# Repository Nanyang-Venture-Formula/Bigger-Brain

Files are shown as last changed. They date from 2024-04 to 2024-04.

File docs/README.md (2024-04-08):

# Bigger Brain (Rev 2.1)

This repository contains all documents regarding the Bigger Brain board.

### Shortcuts
- [Schematics](#Schematics)
- [Assembly](#Assembly)
- [Renders](#Renders)
- [Bom](#Bom)

---

## Schematics



## Assembly




## Renders

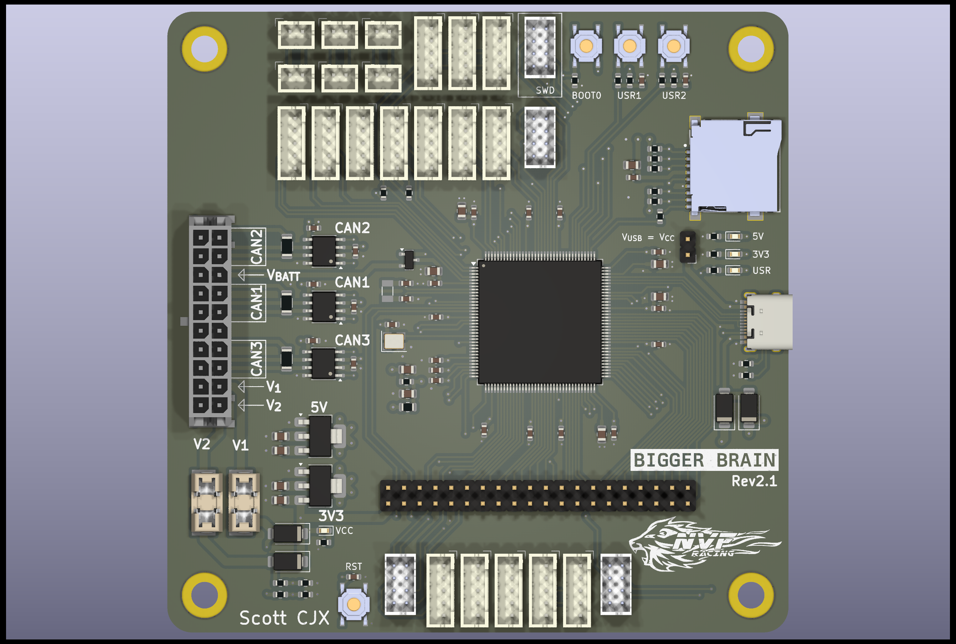
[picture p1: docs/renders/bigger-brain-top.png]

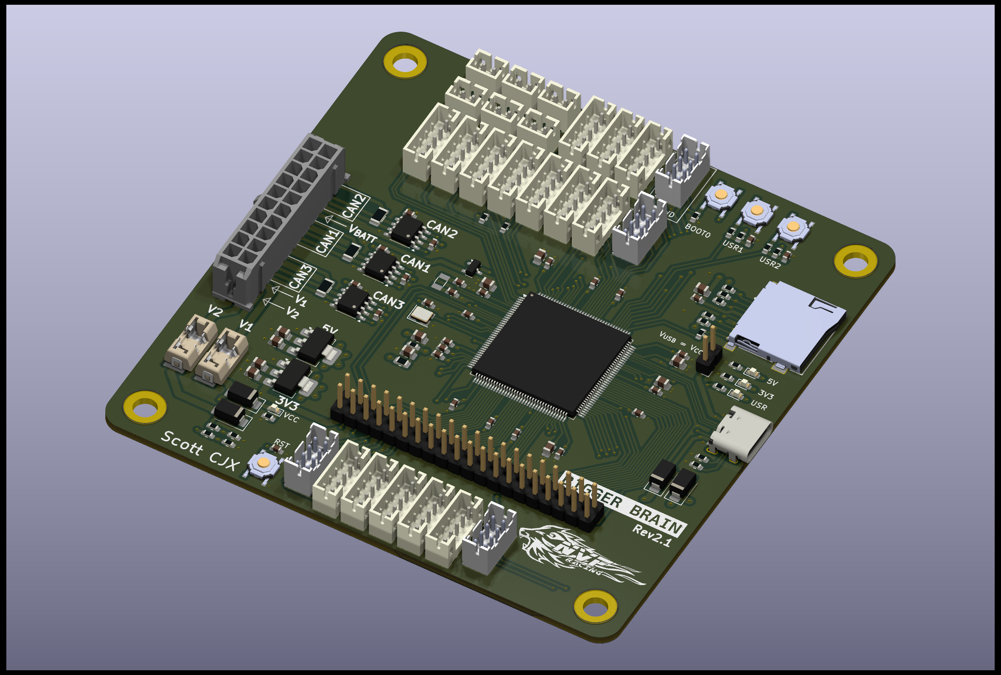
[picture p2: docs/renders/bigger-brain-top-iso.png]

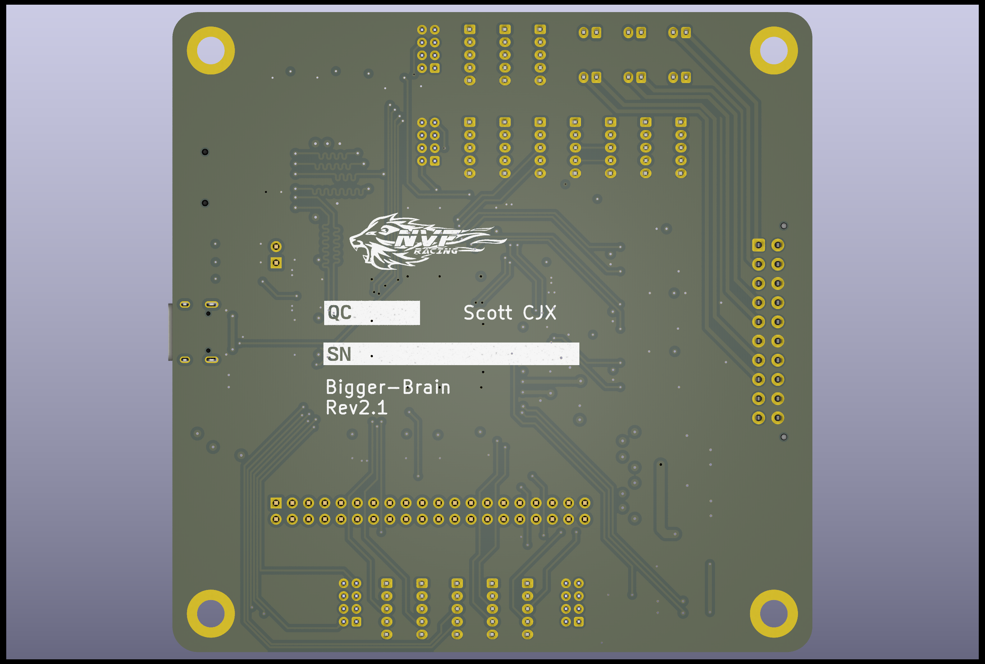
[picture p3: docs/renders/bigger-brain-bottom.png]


## Bom

[Interactive BOM](./ibom/ibom.html)

[BOM](./bom/bigger-brain.csv)

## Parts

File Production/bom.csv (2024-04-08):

Designator | Footprint | Quantity | Value | LCSC Part #
C101, C201, C202, C203, C204, C205, C206, C207, C208, C209, C210, C211, C213, C215, C217, C221, C301, C401, C402, C403, C501, C502, C601, C602, C701, C702 | 0603 | 26 | 100n | C14663
C103, C104 | 0603 | 2 | 15p | C1644
C212 | 0805 | 1 | 4u7 | C1779
C214, C216, C218, C222, C302 | 0805 | 5 | 1u | C28323
C219, C220, C223, C224, C227, C228 | 0805 | 6 | 2u2 | C377773
D201 | SOT-23 | 1 | BAV70 | C68978
D202, D203, D401, D402 | D_SMA | 4 | SS14 | C2480
D403 | 0603 | 1 | GREEN | C434423
D404 | 0603 | 1 | RED | C2286
D405, D406 | 0603 | 2 | BLUE | C965807
F201, F202 | FUSE-Littelfuse_Nano2_154x | 2 | 1A | C206910
H401, H402, H403, H404 | MountingHole_4.3mm_M4_DIN965_Pad_TopBottom | 4 | M4 Pad | -
J301 | TFCard_TF-01A | 1 | TF-01A | C91145
J401 | USBC_HRO_TYPE-C-31-M-12 | 1 | USB_C | C165948
J402 | MicroFit_02x10V-H | 1 | Molex_Micro-Fit_3.0_43045-2012_2x10_P3.00mm_Vertical | C485575
J403 | 2.54mm2x20V-H | 1 | 2x20V-H | C2894981
J404, J405, J406, J410, J411, J412 | PH_01x02V-H | 6 | Conn_01x02 | C2683610
J407, J408, J409 | PH_01x05V-H | 3 | I2C Breakout | C157993
J413, J415, J416, J417, J418, J419, J422, J425, J426 | PH_01x05V-H | 9 | Generic Breakout | C157993
J414, J423, J424 | PH_01x05V-H | 3 | UART Breakout | C157993
J420, J421, J427 | PHD_02x04V-H | 3 | SPI Breakout | C157975
JP401 | PinHeader_1x02_P2.54mm_Vertical | 1 | Jumper_2_Open | -
L201 | 0805 | 1 | 100MHz | C1015
R101, R102, R202, R204, R401, R402 | 0603 | 6 | 5k1 | C23186
R201 | 0603 | 1 | 47 | C23182
R203, R205, R410, R411, R414 | 0603 | 5 | 1k | C21190
R301, R302, R303, R304, R305 | 0603 | 5 | 47k | C25819
R306, R406, R407, R408 | 0603 | 4 | 10k | C25804
R403, R404, R405 | 1206 | 3 | 120 | C17909
R409, R412, R413 | 0603 | 3 | 300 | C23025
SW401, SW402, SW403, SW404 | PushBtn_TS-1187A-B-A-B | 4 | SW_Push | C318884
SWD401 | PHD_02x04V-H | 1 | ~ | C157975
U101 | LQFP-144_20x20mm_P0.5mm | 1 | STM32H723ZGTx | C730146
U201 | SOT-223-3_TabPin2 | 1 | AMS1117-3.3 | C6186
U203 | SOT-223-3_TabPin2 | 1 | AMS1117-5.0 | C6187
U501, U601, U701 | SOIC-8_3.9x4.9mm_P1.27mm | 3 | TJA1042T-3 | C132227
X101 | Crystal_SMD_3225-4Pin_3.2x2.5mm | 1 | 25MHz ±10ppm | C669088
Y101 | Crystal_SMD_3215-2Pin_3.2x1.5mm | 1 | 32.768kHz 12.5pF ±20ppm | C32346

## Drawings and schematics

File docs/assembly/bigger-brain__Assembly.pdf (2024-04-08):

1 | 2 | 3 | 4 | 5 | 6

A

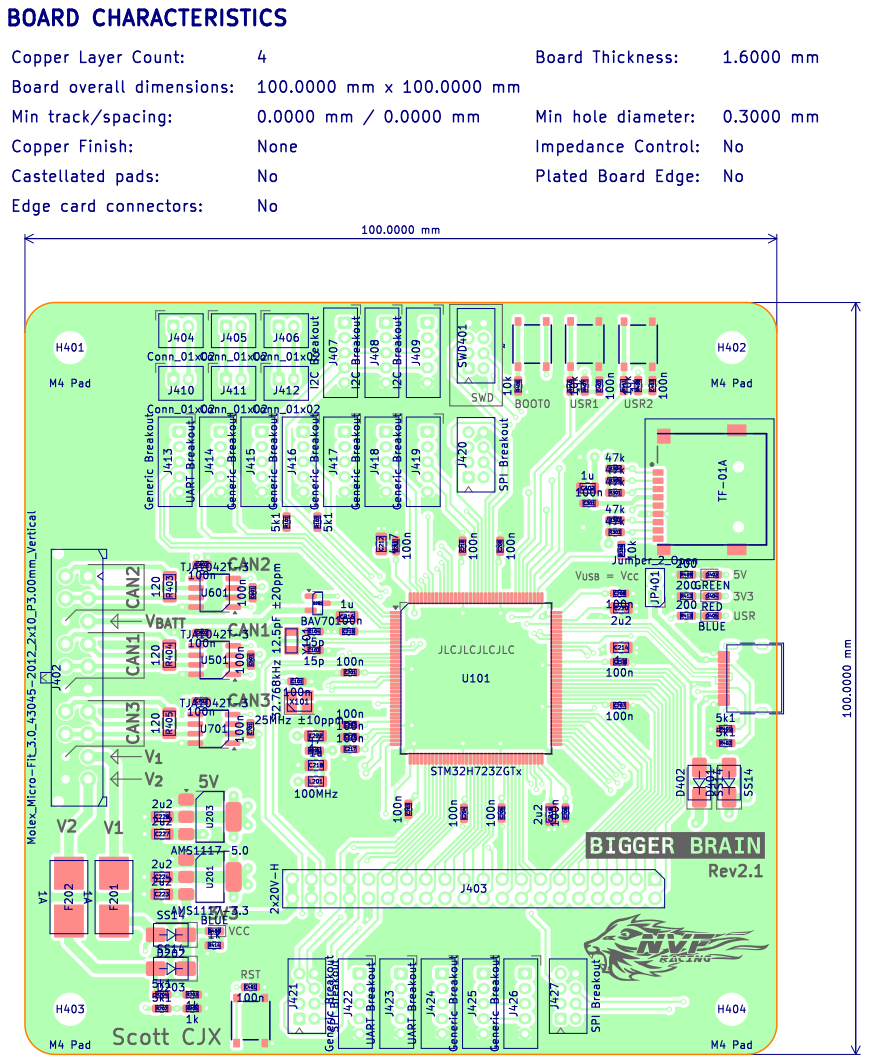
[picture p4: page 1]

File: bigger-brain.kicad_pcb Sheet: Scott CJX

Id: 1/1 Title: Bigger Brain

1 | 2 | 3 | 4 | 5 | 6

A

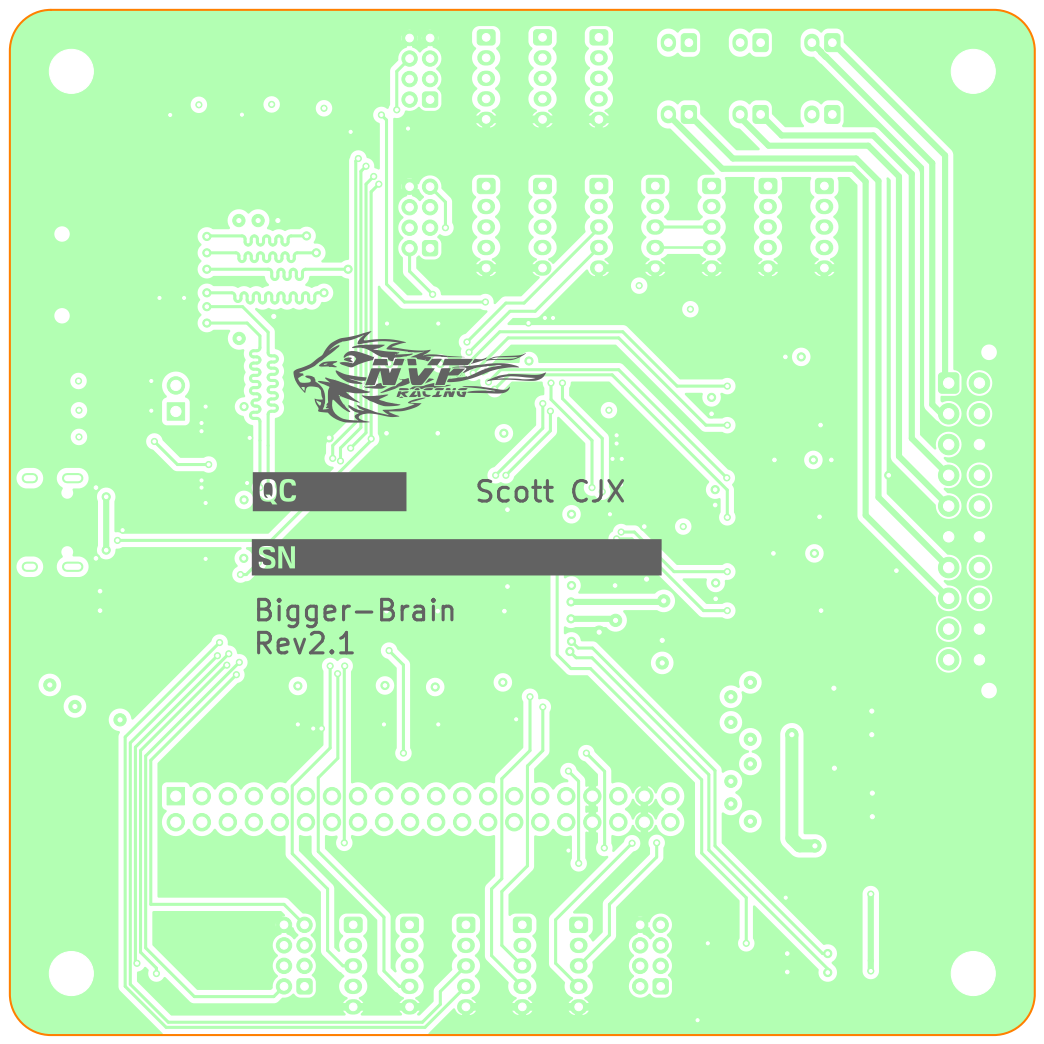
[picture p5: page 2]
Bigger-Brain Rev2.1; Scott; CJX; D Date: 2024-04-08 KiCad; E.D.A. 8.0.1 Size: A4; Rev: 2.1

File: bigger-brain.kicad_pcb Sheet: Scott CJX

Id: 1/1 Title: Bigger Brain

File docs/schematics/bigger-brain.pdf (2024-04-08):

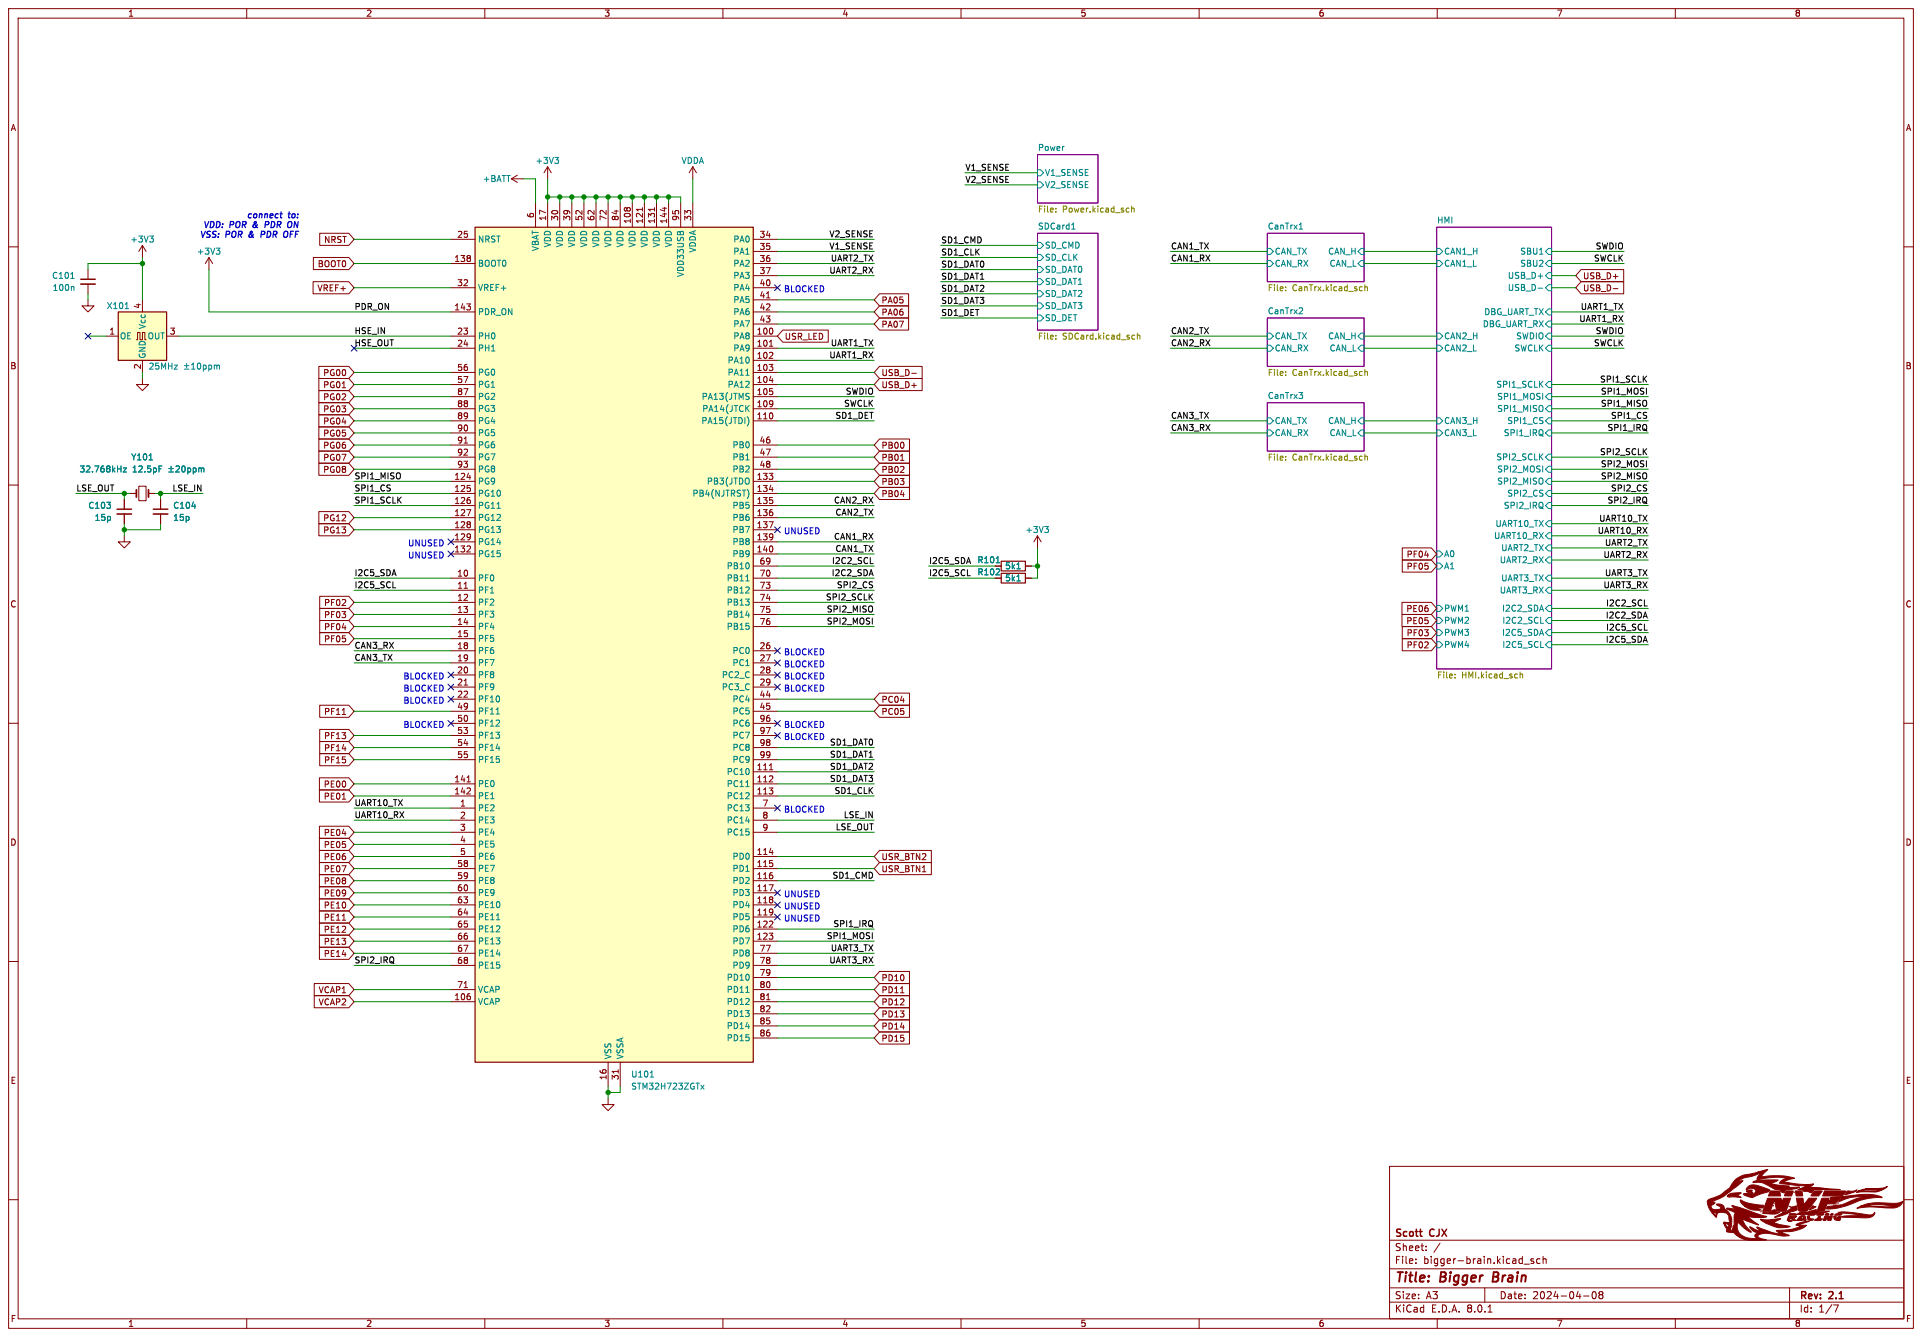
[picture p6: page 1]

Power File: Power.kicad_sch VDDA

connect to: VDD: POR & PDR ON

Id: 1/7 Title: Bigger Brain

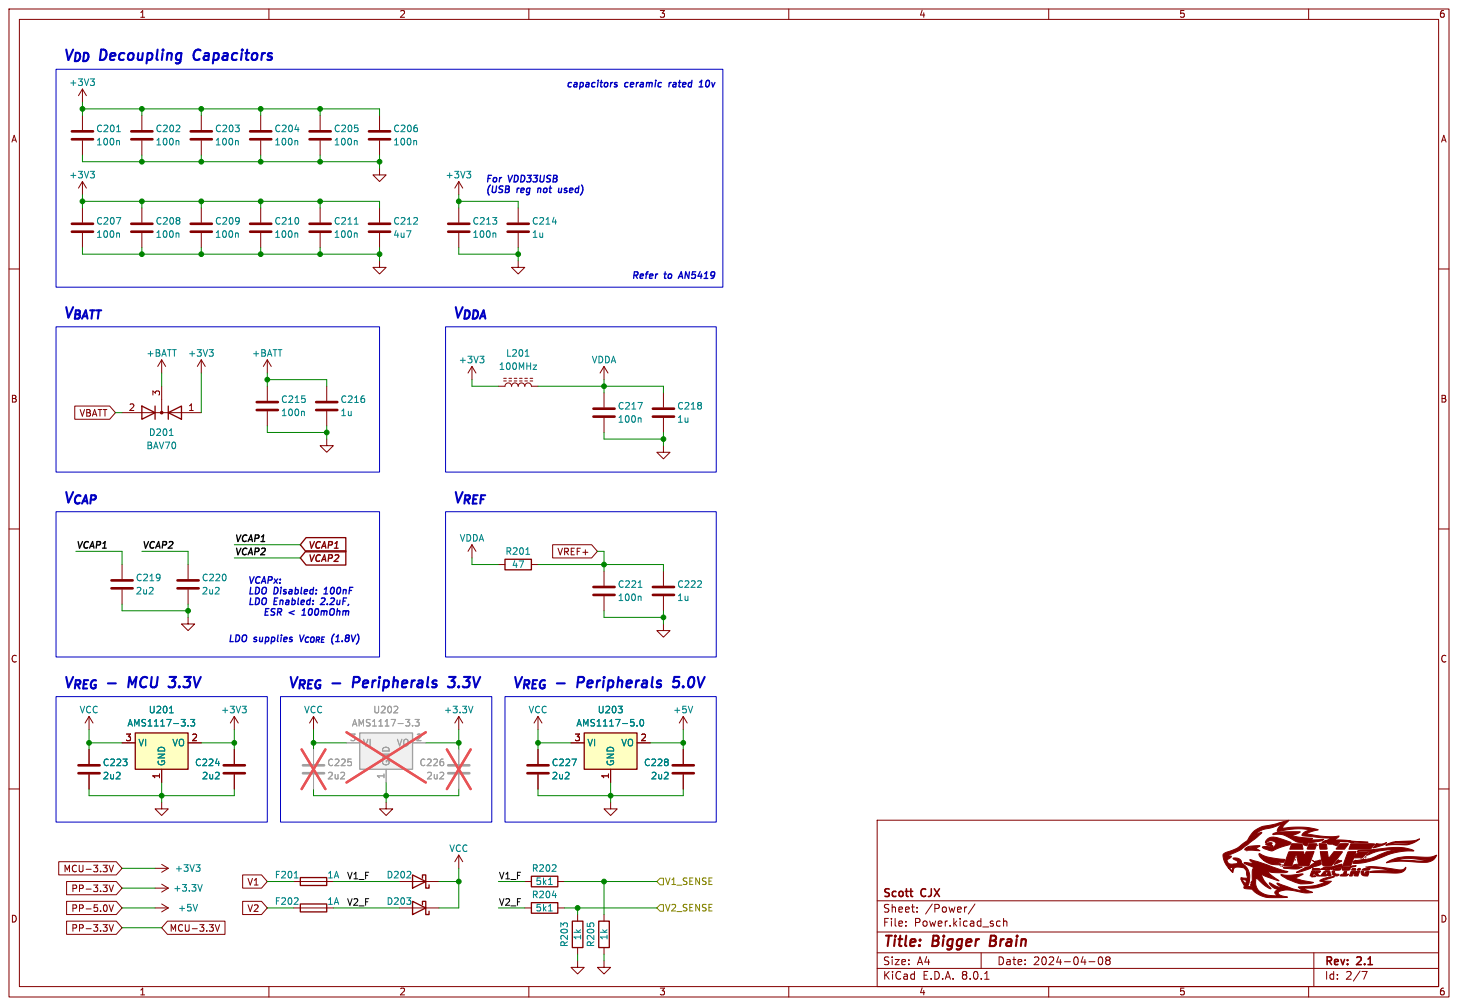
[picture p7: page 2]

capacitors ceramic rated 10v U202 AMS1117-3.3 GND

(USB reg not used)

File: Power.kicad_sch Sheet: /Power/ Scott CJX

Id: 2/7 Title: Bigger Brain

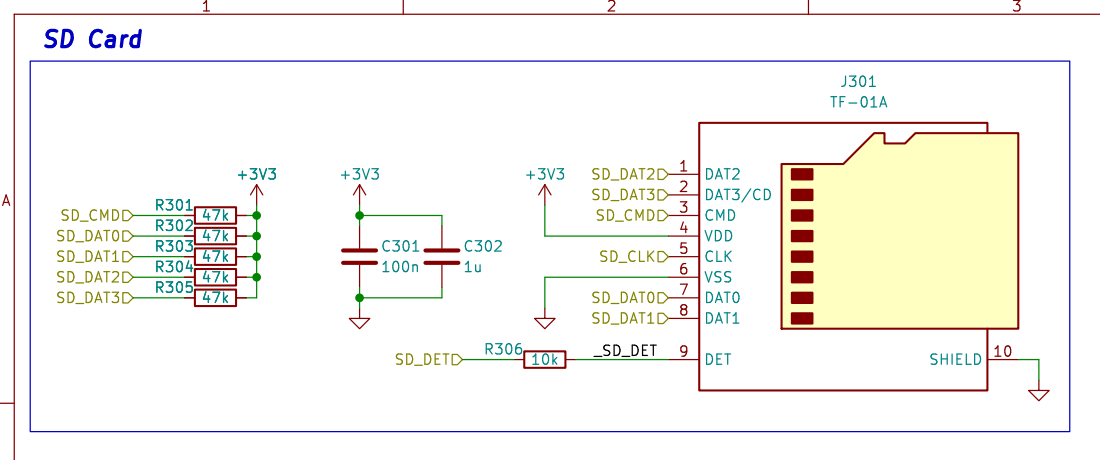
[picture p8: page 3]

File: SDCard.kicad_sch Sheet: /SDCard1/ Scott CJX

Id: 3/7 Title: Bigger Brain

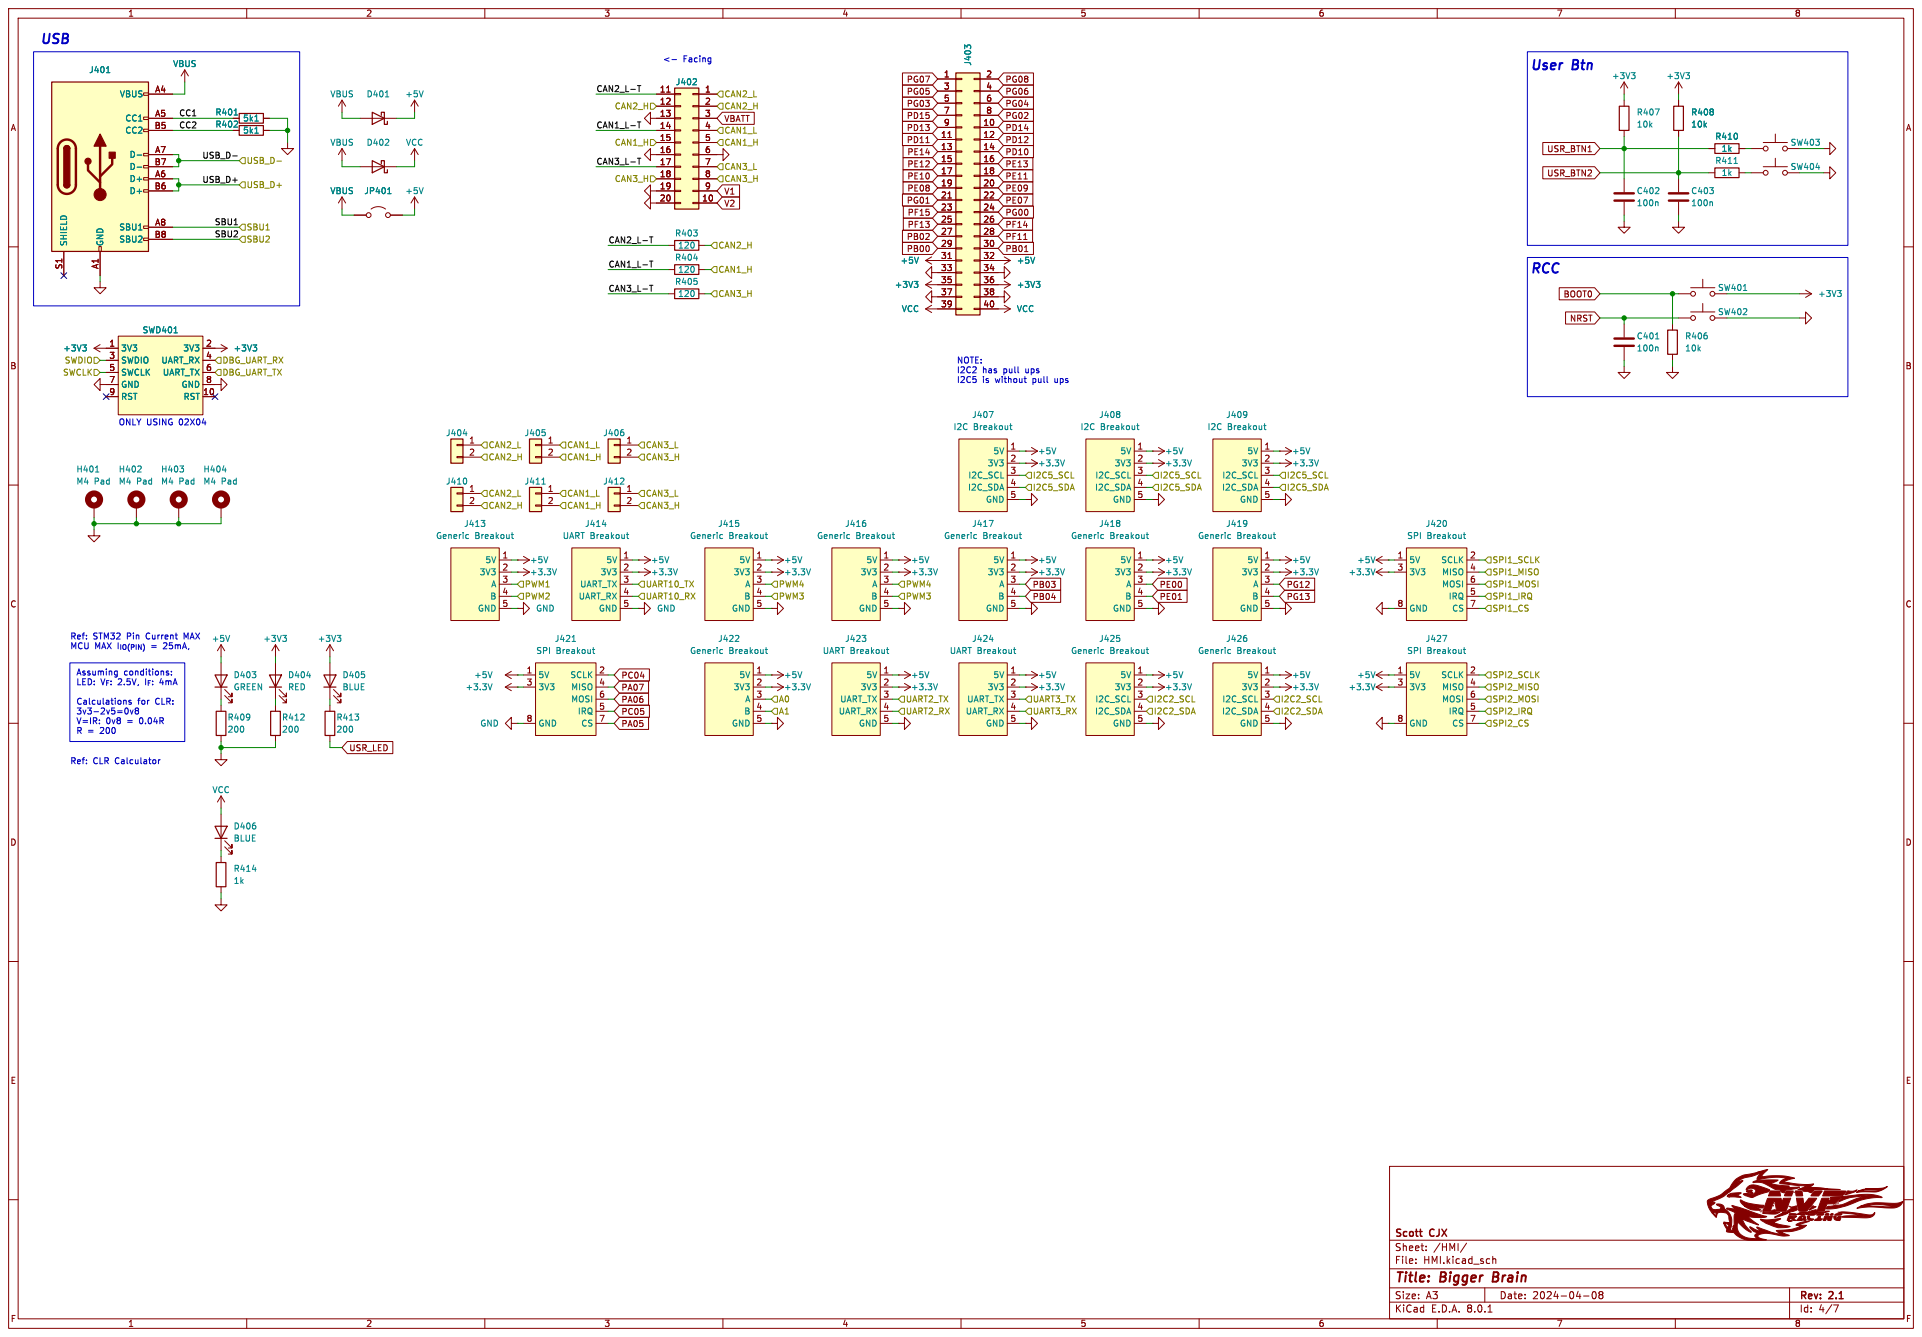
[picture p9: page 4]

I2C5 is without pull ups J403

R = 200 Ref: CLR Calculator Ref: STM32 Pin Current MAX MCU MAX I_{IO(PIN)}= 25mA,

IRQ 5 MOSI 6 CS 7 GND 8

Id: 4/7 Title: Bigger Brain

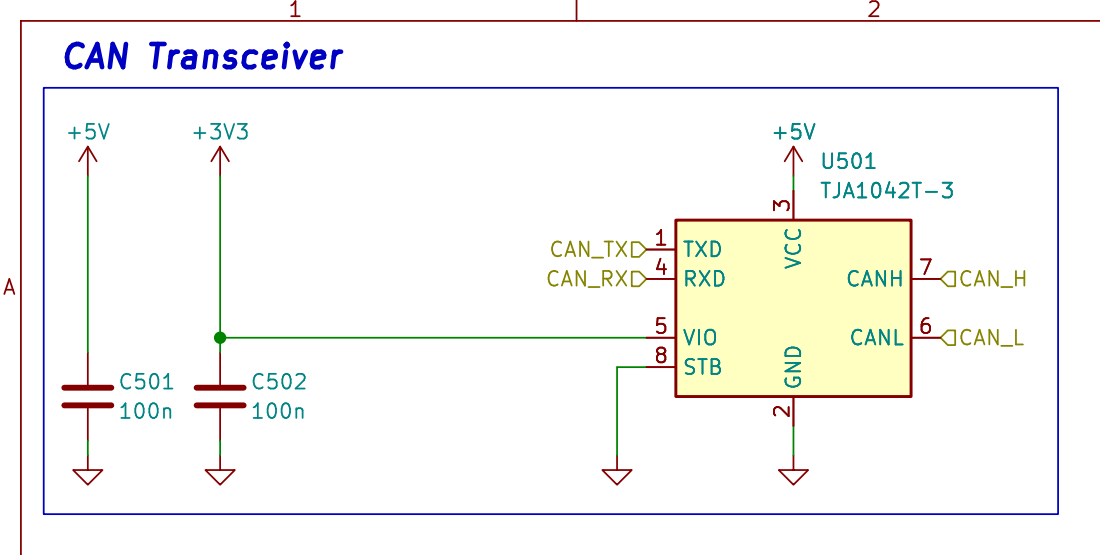
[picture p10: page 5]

3 RXD 4 VIO 5 CANL 6 CANH 7 STB 8 U501 TJA1042T-3 +5V C501

3 RXD 4 VIO 5 CANL 6 CANH 7 STB 8 +5V

File: CanTrx.kicad_sch Sheet: /CanTrx1/ Scott CJX

Id: 5/7 Title: Bigger Brain

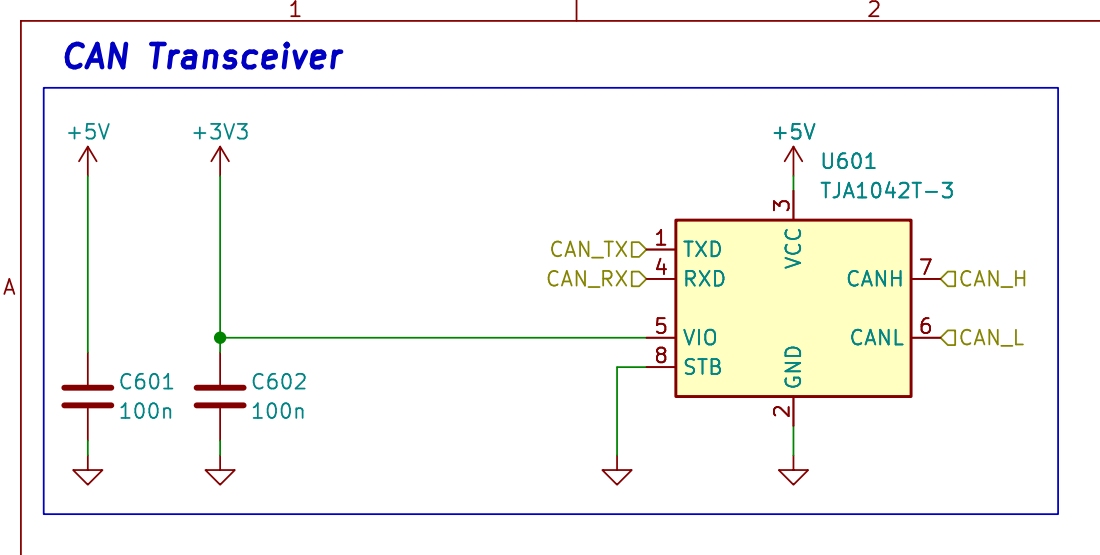
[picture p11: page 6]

3 RXD 4 VIO 5 CANL 6 CANH 7 STB 8 U601 TJA1042T-3 +5V C601

3 RXD 4 VIO 5 CANL 6 CANH 7 STB 8 +5V

File: CanTrx.kicad_sch Sheet: /CanTrx2/ Scott CJX

Id: 6/7 Title: Bigger Brain

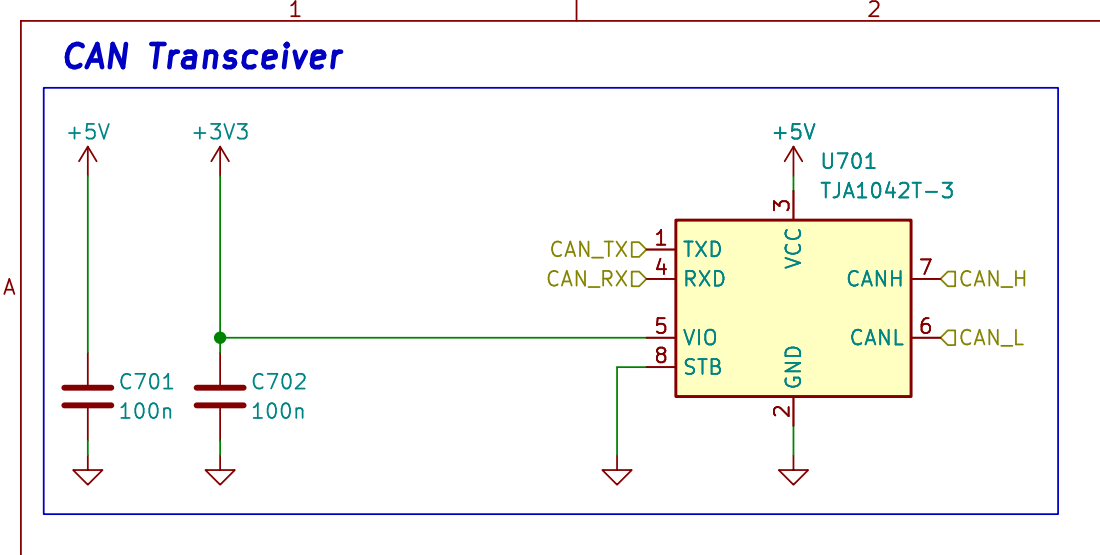
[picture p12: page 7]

3 RXD 4 VIO 5 CANL 6 CANH 7 STB 8 U701 TJA1042T-3 +5V +3V3 +5V C701

3 RXD 4 VIO 5 CANL 6 CANH 7 STB 8 +5V

File: CanTrx.kicad_sch Sheet: /CanTrx3/ Scott CJX

Id: 7/7 Title: Bigger Brain

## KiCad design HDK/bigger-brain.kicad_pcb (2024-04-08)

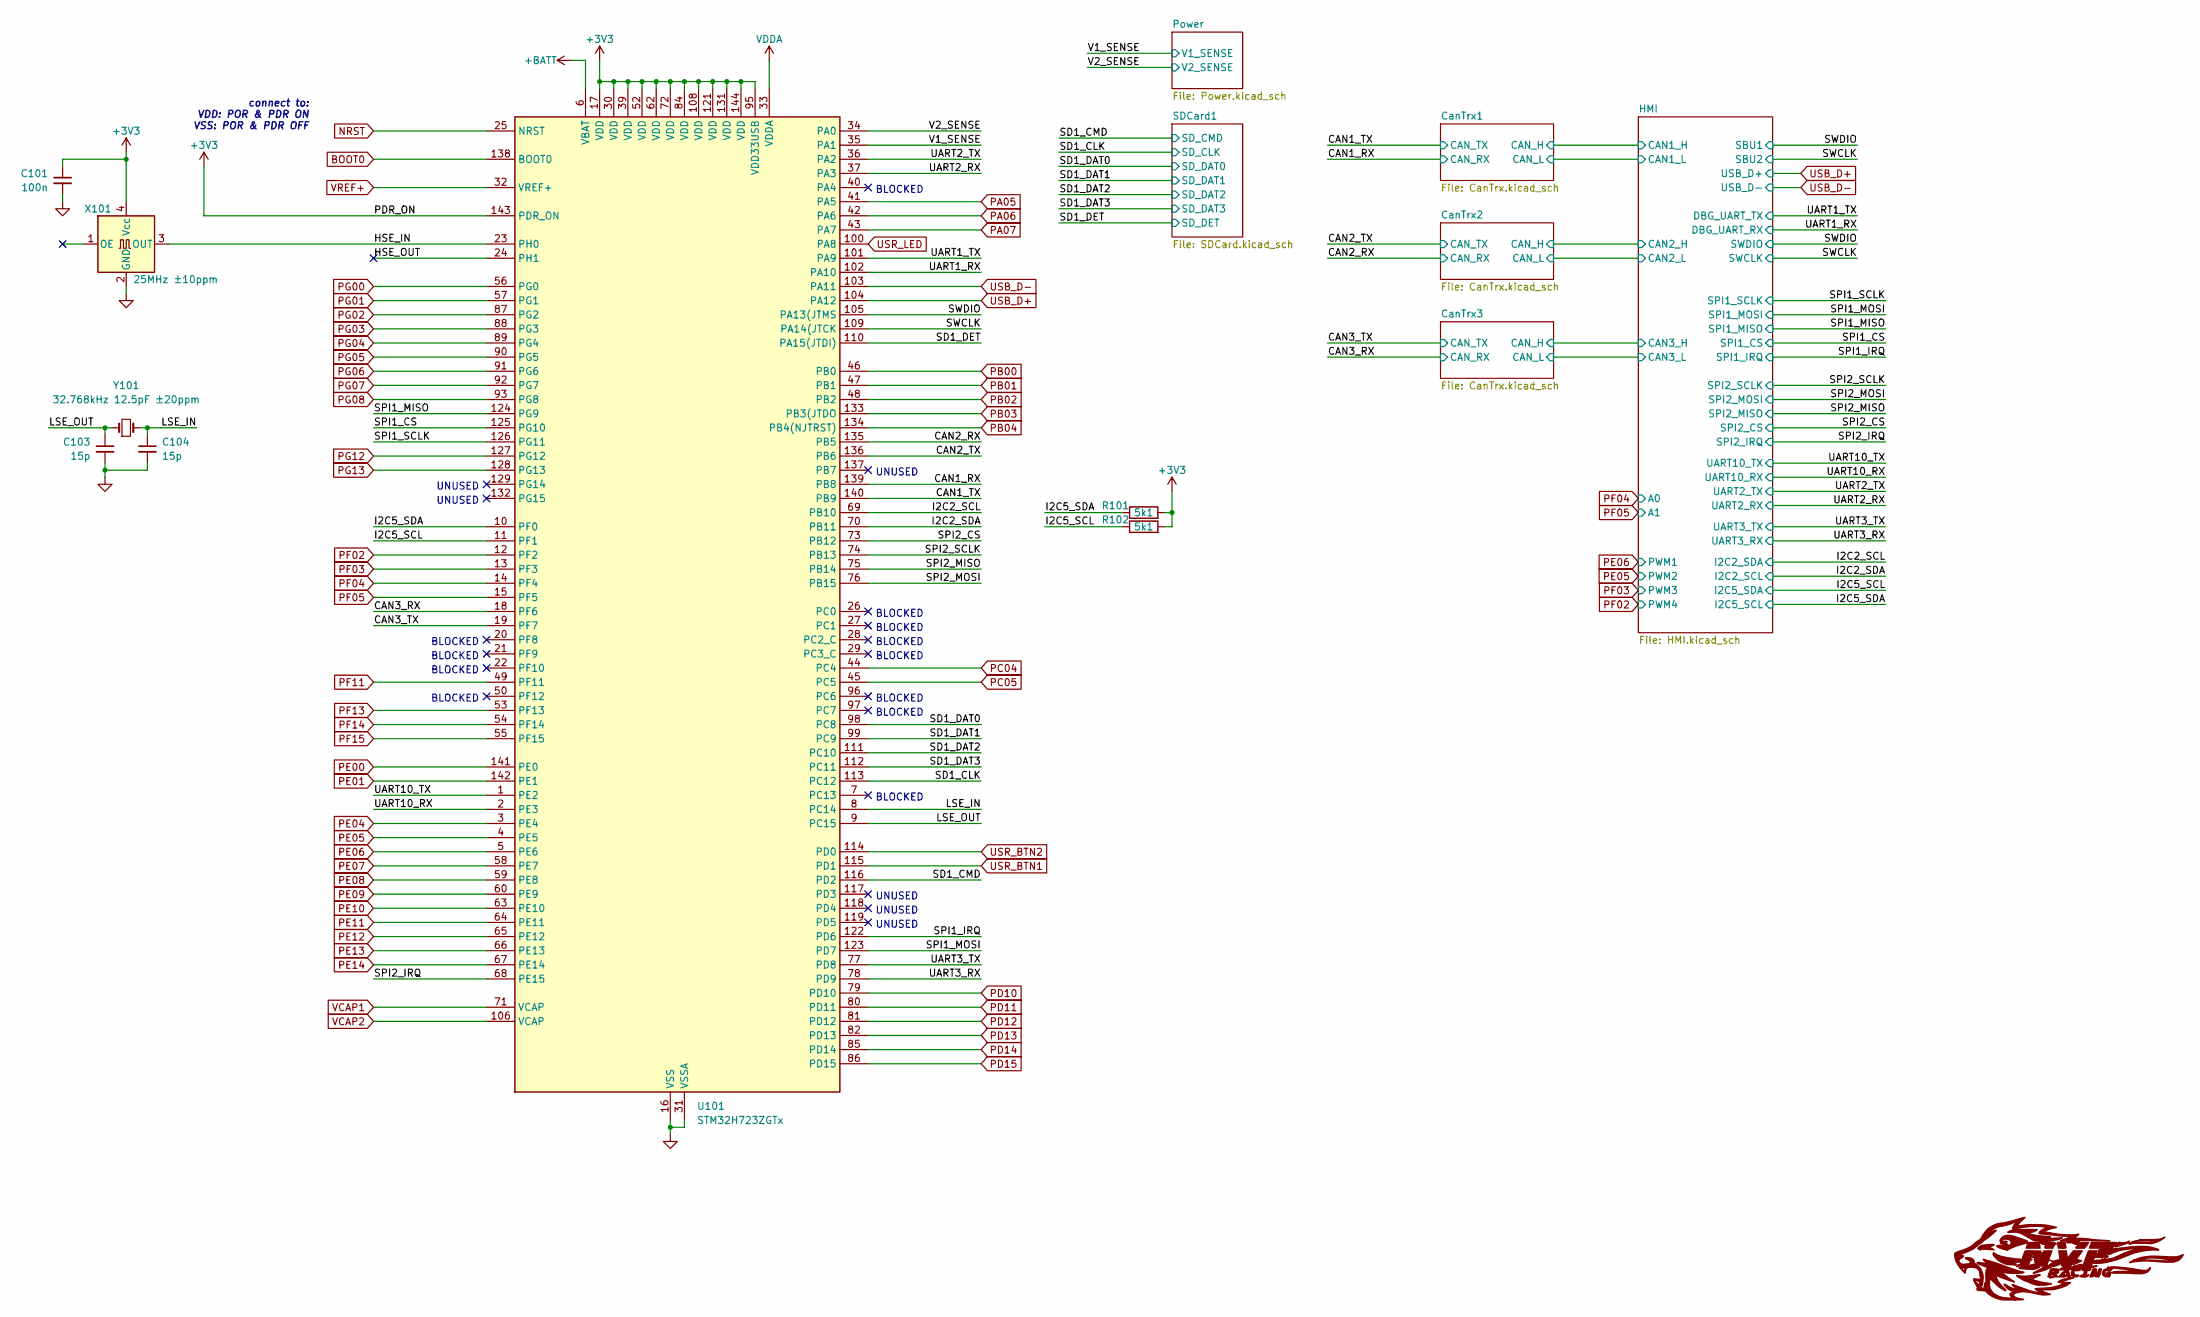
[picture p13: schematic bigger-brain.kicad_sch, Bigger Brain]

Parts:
C101: 100n; C_0603_1608Metric; LCSC C14663
C103, C104: 15p; C_0603_1608Metric; LCSC C1644
R101, R102: 5k1; R_0603_1608Metric; LCSC C23186
U101: STM32H723ZGTx; LQFP-144_20x20mm_P0.5mm; LCSC C730146
X101: 25MHz ±10ppm; Crystal_SMD_3225-4Pin_3.2x2.5mm; LCSC C669088
Y101: 32.768kHz 12.5pF ±20ppm; Crystal_SMD_3215-2Pin_3.2x1.5mm; LCSC C32346

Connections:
+BATT: U101.6 (VBAT); also elsewhere on the board
/CAN1_RX: U101.139 (PB8); also elsewhere on the board
/CAN1_TX: U101.140 (PB9); also elsewhere on the board
/CAN2_RX: U101.135 (PB5); also elsewhere on the board
/CAN2_TX: U101.136 (PB6); also elsewhere on the board
/CAN3_RX: U101.18 (PF6); also elsewhere on the board
/CAN3_TX: U101.19 (PF7); also elsewhere on the board
/HSE_IN: U101.23 (PH0), X101.3 (OUT)
/HSE_OUT: U101.24 (PH1)
/I2C2_SCL: U101.69 (PB10); also elsewhere on the board
/I2C2_SDA: U101.70 (PB11); also elsewhere on the board
/I2C5_SCL: R102.1, U101.11 (PF1); also elsewhere on the board
/I2C5_SDA: R101.1, U101.10 (PF0); also elsewhere on the board
/LSE_IN: C104.1, U101.8 (PC14), Y101.2
/LSE_OUT: C103.1, U101.9 (PC15), Y101.1
/SD1_CLK: U101.113 (PC12); also elsewhere on the board
/SD1_CMD: U101.116 (PD2); also elsewhere on the board
/SD1_DAT0: U101.98 (PC8); also elsewhere on the board
/SD1_DAT1: U101.99 (PC9); also elsewhere on the board
/SD1_DAT2: U101.111 (PC10); also elsewhere on the board
/SD1_DAT3: U101.112 (PC11); also elsewhere on the board
/SD1_DET: U101.110 (PA15(JTDI)); also elsewhere on the board
/SPI1_CS: U101.125 (PG10); also elsewhere on the board
/SPI1_IRQ: U101.122 (PD6); also elsewhere on the board
/SPI1_MISO: U101.124 (PG9); also elsewhere on the board
/SPI1_MOSI: U101.123 (PD7); also elsewhere on the board
/SPI1_SCLK: U101.126 (PG11); also elsewhere on the board
/SPI2_CS: U101.73 (PB12); also elsewhere on the board
/SPI2_IRQ: U101.68 (PE15); also elsewhere on the board
/SPI2_MISO: U101.75 (PB14); also elsewhere on the board
/SPI2_MOSI: U101.76 (PB15); also elsewhere on the board
/SPI2_SCLK: U101.74 (PB13); also elsewhere on the board
/SWCLK: U101.109 (PA14(JTCK); also elsewhere on the board
/SWDIO: U101.105 (PA13(JTMS); also elsewhere on the board
/UART1_RX: U101.102 (PA10); also elsewhere on the board
/UART1_TX: U101.101 (PA9); also elsewhere on the board
/UART2_RX: U101.37 (PA3); also elsewhere on the board
/UART2_TX: U101.36 (PA2); also elsewhere on the board
/UART3_RX: U101.78 (PD9); also elsewhere on the board
/UART3_TX: U101.77 (PD8); also elsewhere on the board
/UART10_RX: U101.2 (PE3); also elsewhere on the board
/UART10_TX: U101.1 (PE2); also elsewhere on the board
/V1_SENSE: U101.35 (PA1); also elsewhere on the board
/V2_SENSE: U101.34 (PA0); also elsewhere on the board
BOOT0: U101.138 (BOOT0); also elsewhere on the board
GND: C101.2, C103.2, C104.2, U101.16 (VSS), U101.31 (VSSA), U101.38 (VSS), U101.51 (VSS), U101.61 (VSS), U101.83 (VSS), U101.94 (VSS), U101.107 (VSS), U101.120 (VSS), U101.130 (VSS), X101.2 (GND); also elsewhere on the board
MCU-3.3V: C101.1, R101.2, R102.2, U101.17 (VDD), U101.30 (VDD), U101.39 (VDD), U101.52 (VDD), U101.62 (VDD), U101.72 (VDD), U101.84 (VDD), U101.95 (VDD33USB), U101.108 (VDD), U101.121 (VDD), U101.131 (VDD), U101.143 (PDR_ON), U101.144 (VDD), X101.4 (Vcc); also elsewhere on the board
NRST: U101.25 (NRST); also elsewhere on the board
PA05: U101.41 (PA5); also elsewhere on the board
PA06: U101.42 (PA6); also elsewhere on the board
PA07: U101.43 (PA7); also elsewhere on the board
PB00: U101.46 (PB0); also elsewhere on the board
PB01: U101.47 (PB1); also elsewhere on the board
PB02: U101.48 (PB2); also elsewhere on the board
PB03: U101.133 (PB3(JTDO); also elsewhere on the board
PB04: U101.134 (PB4(NJTRST)); also elsewhere on the board
PC04: U101.44 (PC4); also elsewhere on the board
PC05: U101.45 (PC5); also elsewhere on the board
PD10: U101.79 (PD10); also elsewhere on the board
PD11: U101.80 (PD11); also elsewhere on the board
PD12: U101.81 (PD12); also elsewhere on the board
PD13: U101.82 (PD13); also elsewhere on the board
PD14: U101.85 (PD14); also elsewhere on the board
PD15: U101.86 (PD15); also elsewhere on the board
PE00: U101.141 (PE0); also elsewhere on the board
PE01: U101.142 (PE1); also elsewhere on the board
PE04: U101.3 (PE4)
PE05: U101.4 (PE5); also elsewhere on the board
PE06: U101.5 (PE6); also elsewhere on the board
PE07: U101.58 (PE7); also elsewhere on the board
PE08: U101.59 (PE8); also elsewhere on the board
PE09: U101.60 (PE9); also elsewhere on the board
PE10: U101.63 (PE10); also elsewhere on the board
PE11: U101.64 (PE11); also elsewhere on the board
PE12: U101.65 (PE12); also elsewhere on the board
PE13: U101.66 (PE13); also elsewhere on the board
PE14: U101.67 (PE14); also elsewhere on the board
PF02: U101.12 (PF2); also elsewhere on the board
PF03: U101.13 (PF3); also elsewhere on the board
PF04: U101.14 (PF4); also elsewhere on the board
PF05: U101.15 (PF5); also elsewhere on the board
PF11: U101.49 (PF11); also elsewhere on the board
PF13: U101.53 (PF13); also elsewhere on the board
PF14: U101.54 (PF14); also elsewhere on the board
PF15: U101.55 (PF15); also elsewhere on the board
PG00: U101.56 (PG0); also elsewhere on the board
PG01: U101.57 (PG1); also elsewhere on the board
PG02: U101.87 (PG2); also elsewhere on the board
PG03: U101.88 (PG3); also elsewhere on the board
PG04: U101.89 (PG4); also elsewhere on the board
PG05: U101.90 (PG5); also elsewhere on the board
PG06: U101.91 (PG6); also elsewhere on the board
PG07: U101.92 (PG7); also elsewhere on the board
PG08: U101.93 (PG8); also elsewhere on the board
PG12: U101.127 (PG12); also elsewhere on the board
PG13: U101.128 (PG13); also elsewhere on the board
USB_D+: U101.104 (PA12); also elsewhere on the board
USB_D-: U101.103 (PA11); also elsewhere on the board
USR_BTN1: U101.115 (PD1); also elsewhere on the board
USR_BTN2: U101.114 (PD0); also elsewhere on the board
USR_LED: U101.100 (PA8); also elsewhere on the board
VCAP1: U101.71 (VCAP); also elsewhere on the board
VCAP2: U101.106 (VCAP); also elsewhere on the board
VDDA: U101.33 (VDDA); also elsewhere on the board
VREF+: U101.32 (VREF+); also elsewhere on the board

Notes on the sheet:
UNUSED
BLOCKED
connect to: VDD: POR & PDR ON VSS: POR & PDR OFF

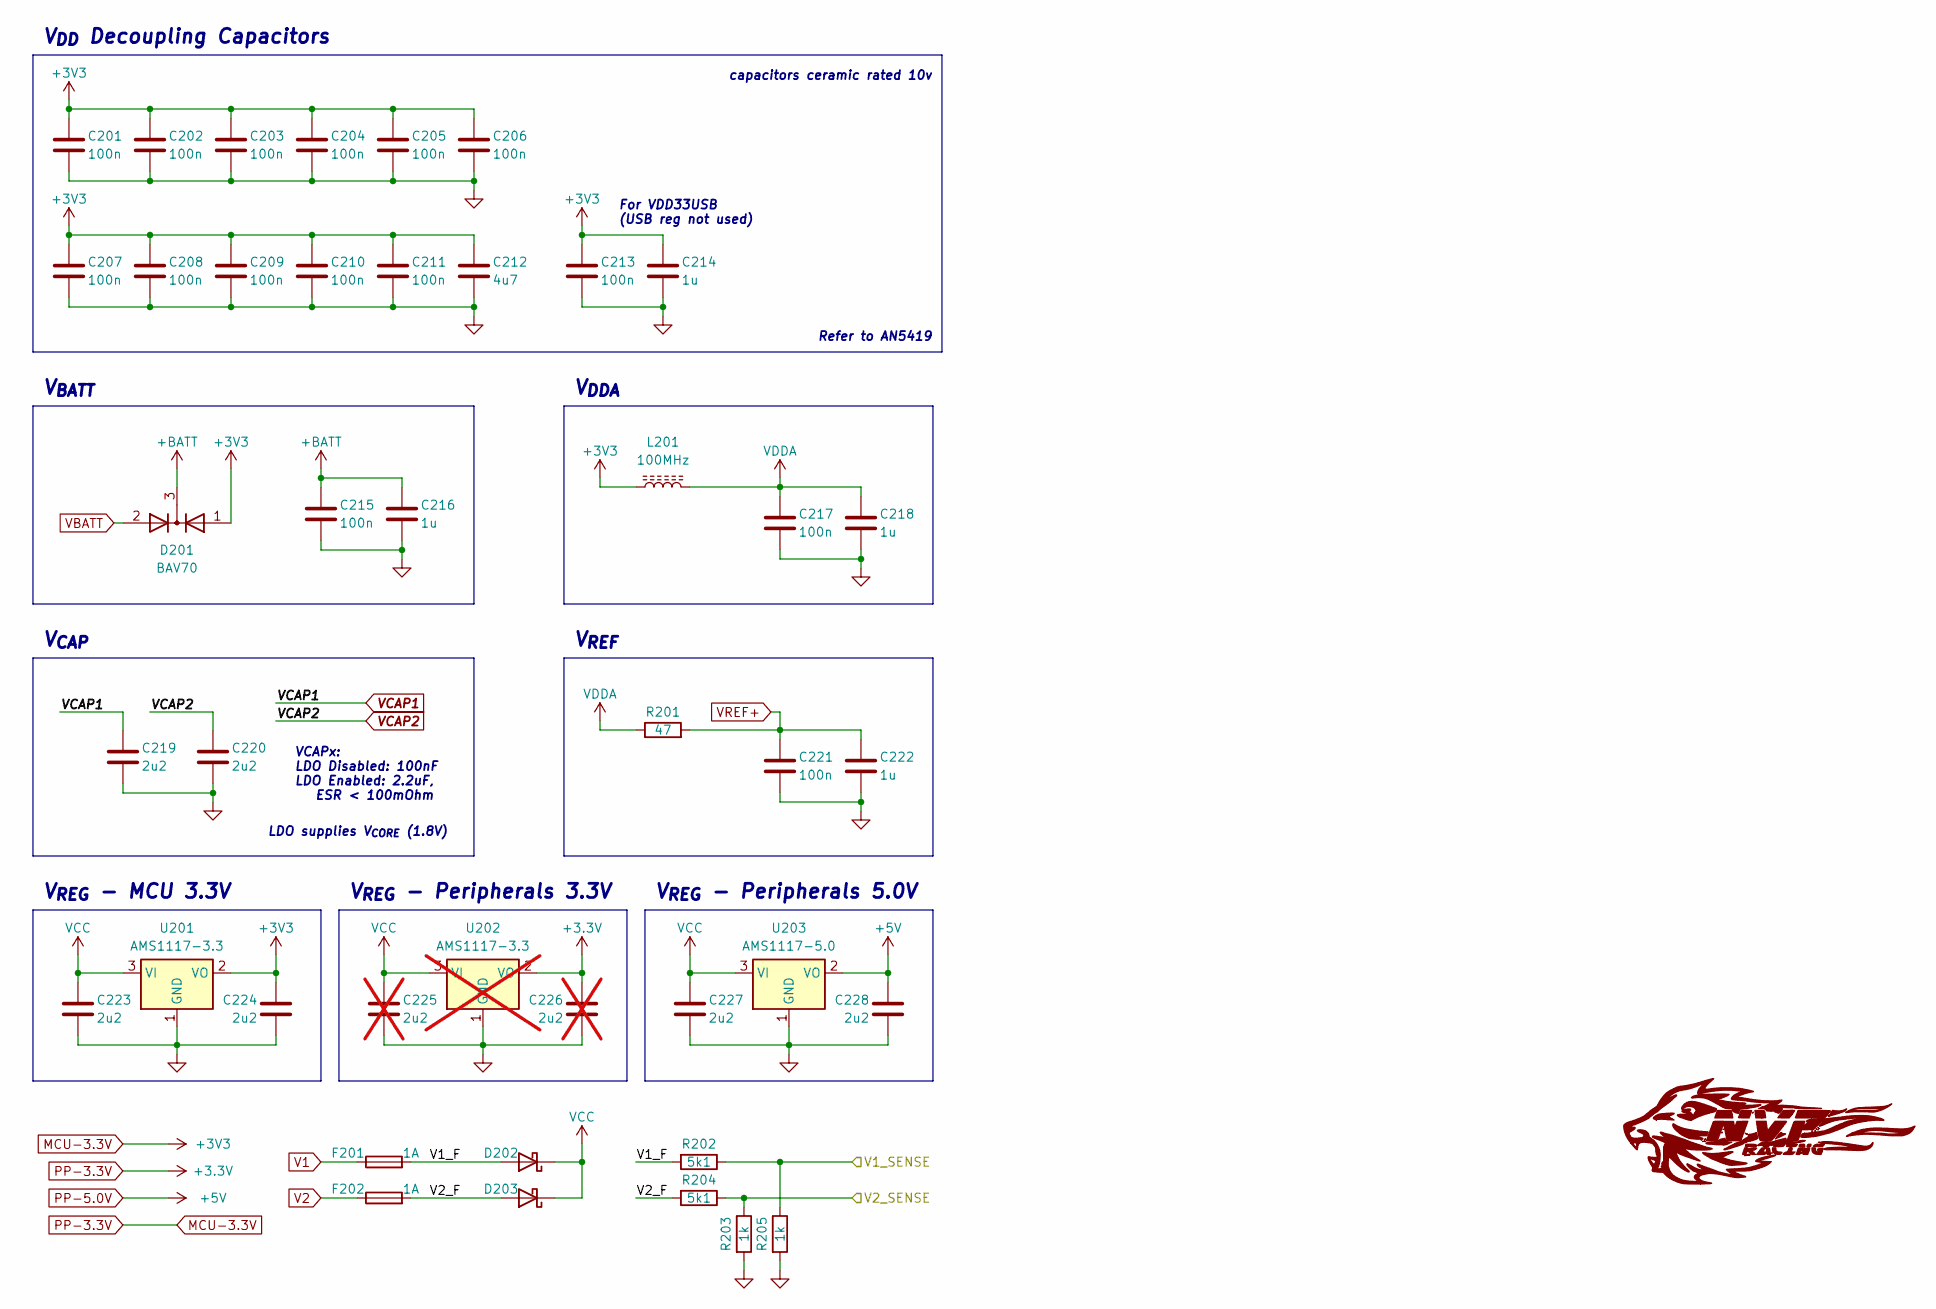
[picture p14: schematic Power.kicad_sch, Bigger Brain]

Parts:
C201, C202, C203, C204, C205, C206, C207, C208, C209, C210, C211, C213, C215, C217, C221: 100n; C_0603_1608Metric; LCSC C14663
C212: 4u7; C_0805_2012Metric; LCSC C1779
C214, C216, C218, C222: 1u; C_0805_2012Metric; LCSC C28323
C219, C220, C223, C224, C227, C228: 2u2; C_0805_2012Metric; LCSC C377773
C225, C226: 2u2; C_0805_2012Metric; LCSC C377773; not fitted
D201: BAV70; SOT-23; LCSC C68978
D202, D203: SS14; D_SMA; LCSC C2480
F201, F202: 1A; FUSE-Littelfuse_Nano2_154x; LCSC C206910
L201: 100MHz; R_0805_2012Metric; LCSC C1015
R201: 47; R_0603_1608Metric; LCSC C23182
R202, R204: 5k1; R_0603_1608Metric; LCSC C23186
R203, R205: 1k; R_0603_1608Metric; LCSC C21190
U201: AMS1117-3.3; SOT-223-3_TabPin2; LCSC C6186
U202: AMS1117-3.3; SOT-223-3_TabPin2; LCSC C6186; not fitted
U203: AMS1117-5.0; SOT-223-3_TabPin2; LCSC C6187

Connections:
+BATT: C215.1, C216.1, D201.3 (K); also elsewhere on the board
/Power/V1_F: D202.2 (A), F201.2, R202.2
/Power/V2_F: D203.2 (A), F202.2, R204.2
/V1_SENSE: R202.1, R205.1; also elsewhere on the board
/V2_SENSE: R203.1, R204.1; also elsewhere on the board
GND: C201.2, C202.2, C203.2, C204.2, C205.2, C206.2, C207.2, C208.2, C209.2, C210.2, C211.2, C212.2, C213.2, C214.2, C215.2, C216.2, C217.2, C218.2, C219.2, C220.2, C221.2, C222.2, C223.2, C224.2, C225.2, C226.2, C227.2, C228.2, R203.2, R205.2, U201.1 (GND), U202.1 (GND), U203.1 (GND); also elsewhere on the board
MCU-3.3V: C201.1, C202.1, C203.1, C204.1, C205.1, C206.1, C207.1, C208.1, C209.1, C210.1, C211.1, C212.1, C213.1, C214.1, C224.1, C226.1, D201.1 (A), L201.1, U201.2 (VO), U202.2 (VO); also elsewhere on the board
PP-5.0V: C228.1, U203.2 (VO); also elsewhere on the board
V1: F201.1; also elsewhere on the board
V2: F202.1; also elsewhere on the board
VBATT: D201.2 (A); also elsewhere on the board
VCAP1: C219.1; also elsewhere on the board
VCAP2: C220.1; also elsewhere on the board
VCC: C223.1, C225.1, C227.1, D202.1 (K), D203.1 (K), U201.3 (VI), U202.3 (VI), U203.3 (VI); also elsewhere on the board
VDDA: C217.1, C218.1, L201.2, R201.1; also elsewhere on the board
VREF+: C221.1, C222.1, R201.2; also elsewhere on the board

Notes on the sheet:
V_{REF}
V_{REG} - Peripherals 3.3V
capacitors ceramic rated 10v
V_{CAP}
LDO supplies V_{CORE} (1.8V)
For VDD33USB (USB reg not used)
VCAPx: LDO Disabled: 100nF LDO Enabled: 2.2uF, ESR < 100mOhm
V_{REG} - Peripherals 5.0V
V_{DDA}
V_{DD} Decoupling Capacitors
Refer to AN5419
V_{REG} - MCU 3.3V
V_{BATT}

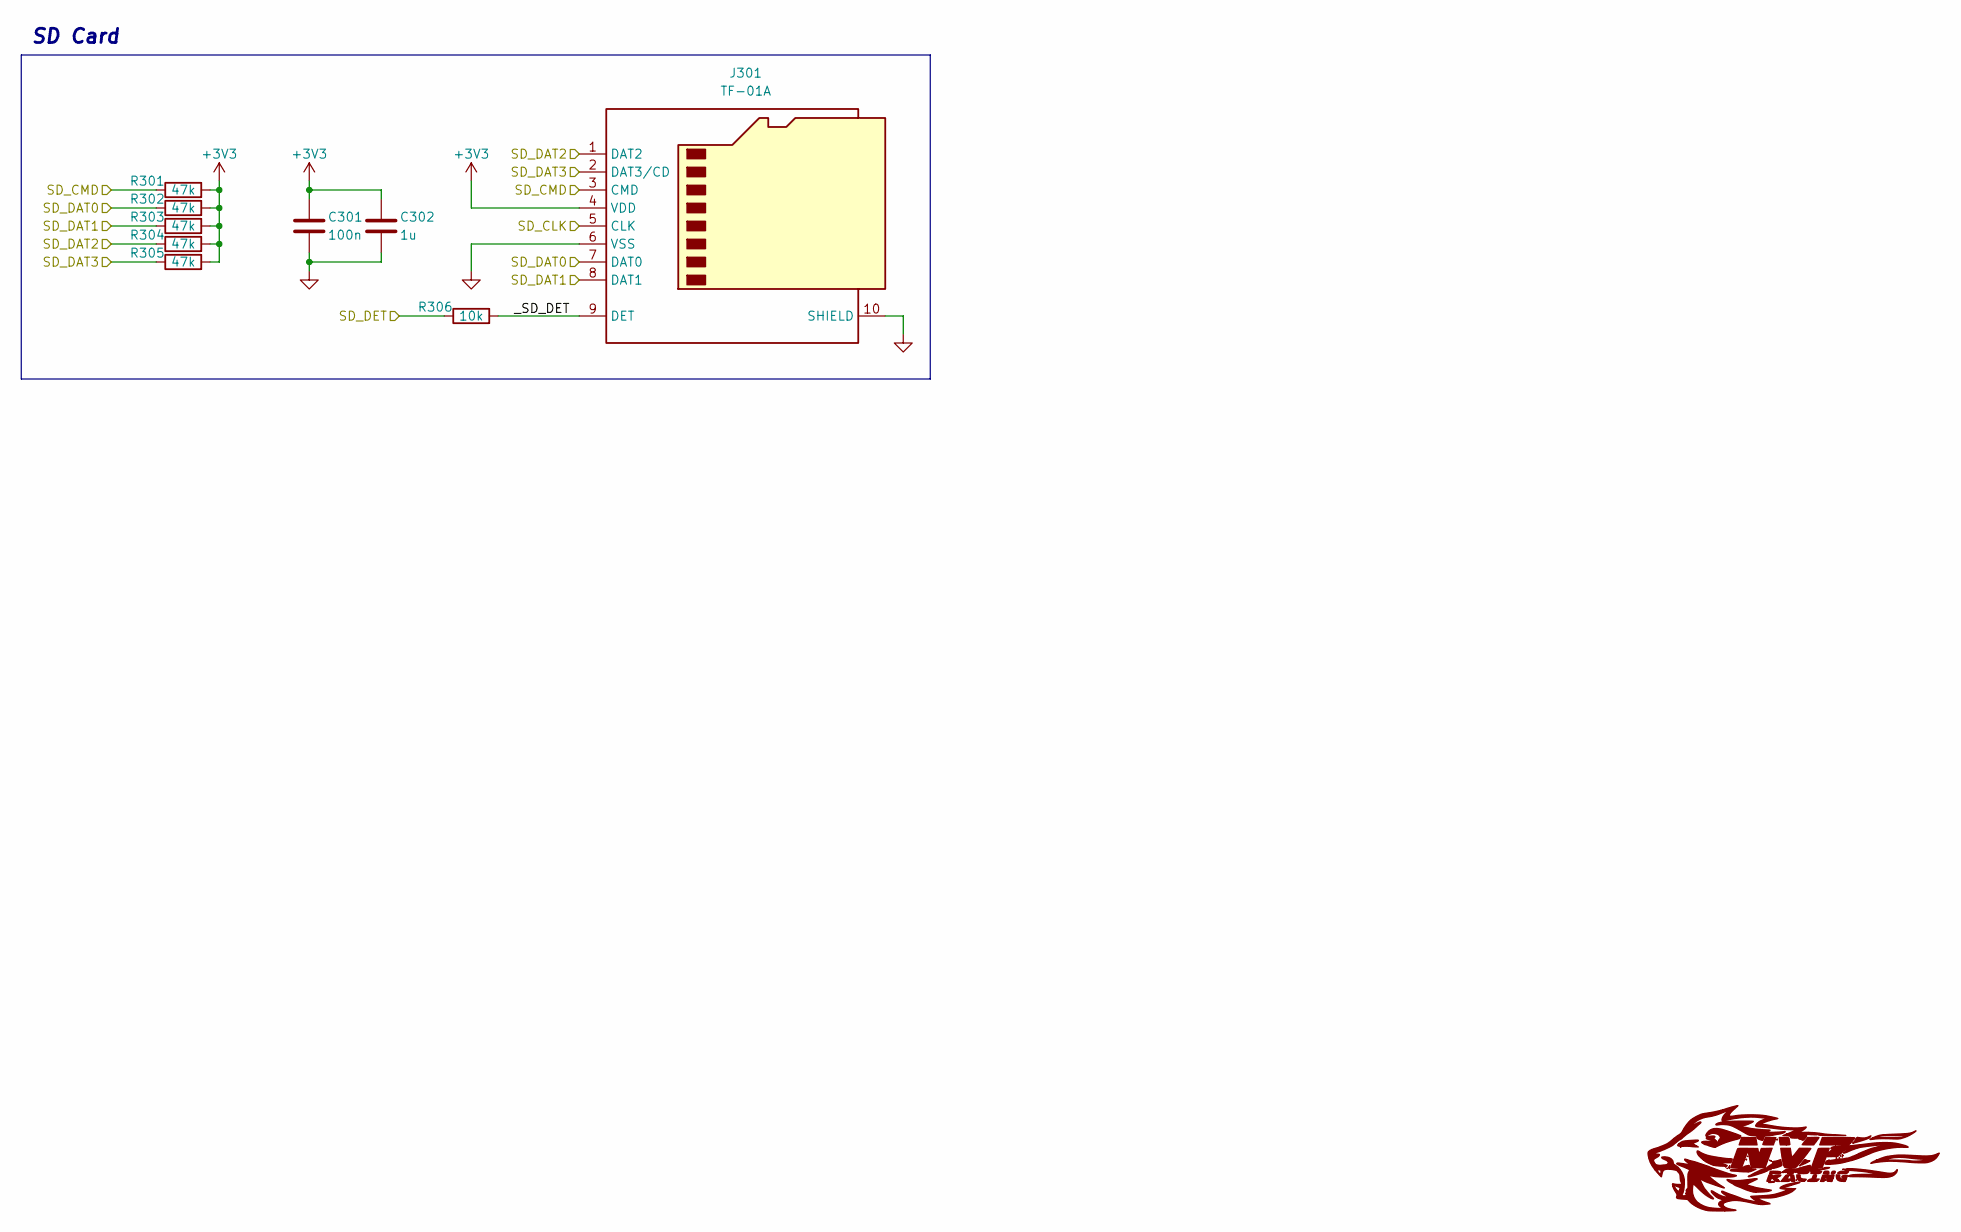
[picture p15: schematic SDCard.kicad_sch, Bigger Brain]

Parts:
C301: 100n; C_0603_1608Metric; LCSC C14663
C302: 1u; C_0805_2012Metric; LCSC C28323
J301: TF-01A; TFCard_TF-01A; LCSC C91145
R301, R302, R303, R304, R305: 47k; R_0603_1608Metric; LCSC C25819
R306: 10k; R_0603_1608Metric; LCSC C25804

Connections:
/SD1_CLK: J301.5 (CLK); also elsewhere on the board
/SD1_CMD: J301.3 (CMD), R301.1; also elsewhere on the board
/SD1_DAT0: J301.7 (DAT0), R302.1; also elsewhere on the board
/SD1_DAT1: J301.8 (DAT1), R303.1; also elsewhere on the board
/SD1_DAT2: J301.1 (DAT2), R304.1; also elsewhere on the board
/SD1_DAT3: J301.2 (DAT3/CD), R305.1; also elsewhere on the board
/SD1_DET: R306.1; also elsewhere on the board
/SDCard1/_SD_DET: J301.9 (DET), R306.2
GND: C301.2, C302.2, J301.6 (VSS), J301.10 (SHIELD); also elsewhere on the board
MCU-3.3V: C301.1, C302.1, J301.4 (VDD), R301.2, R302.2, R303.2, R304.2, R305.2; also elsewhere on the board

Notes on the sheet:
SD Card

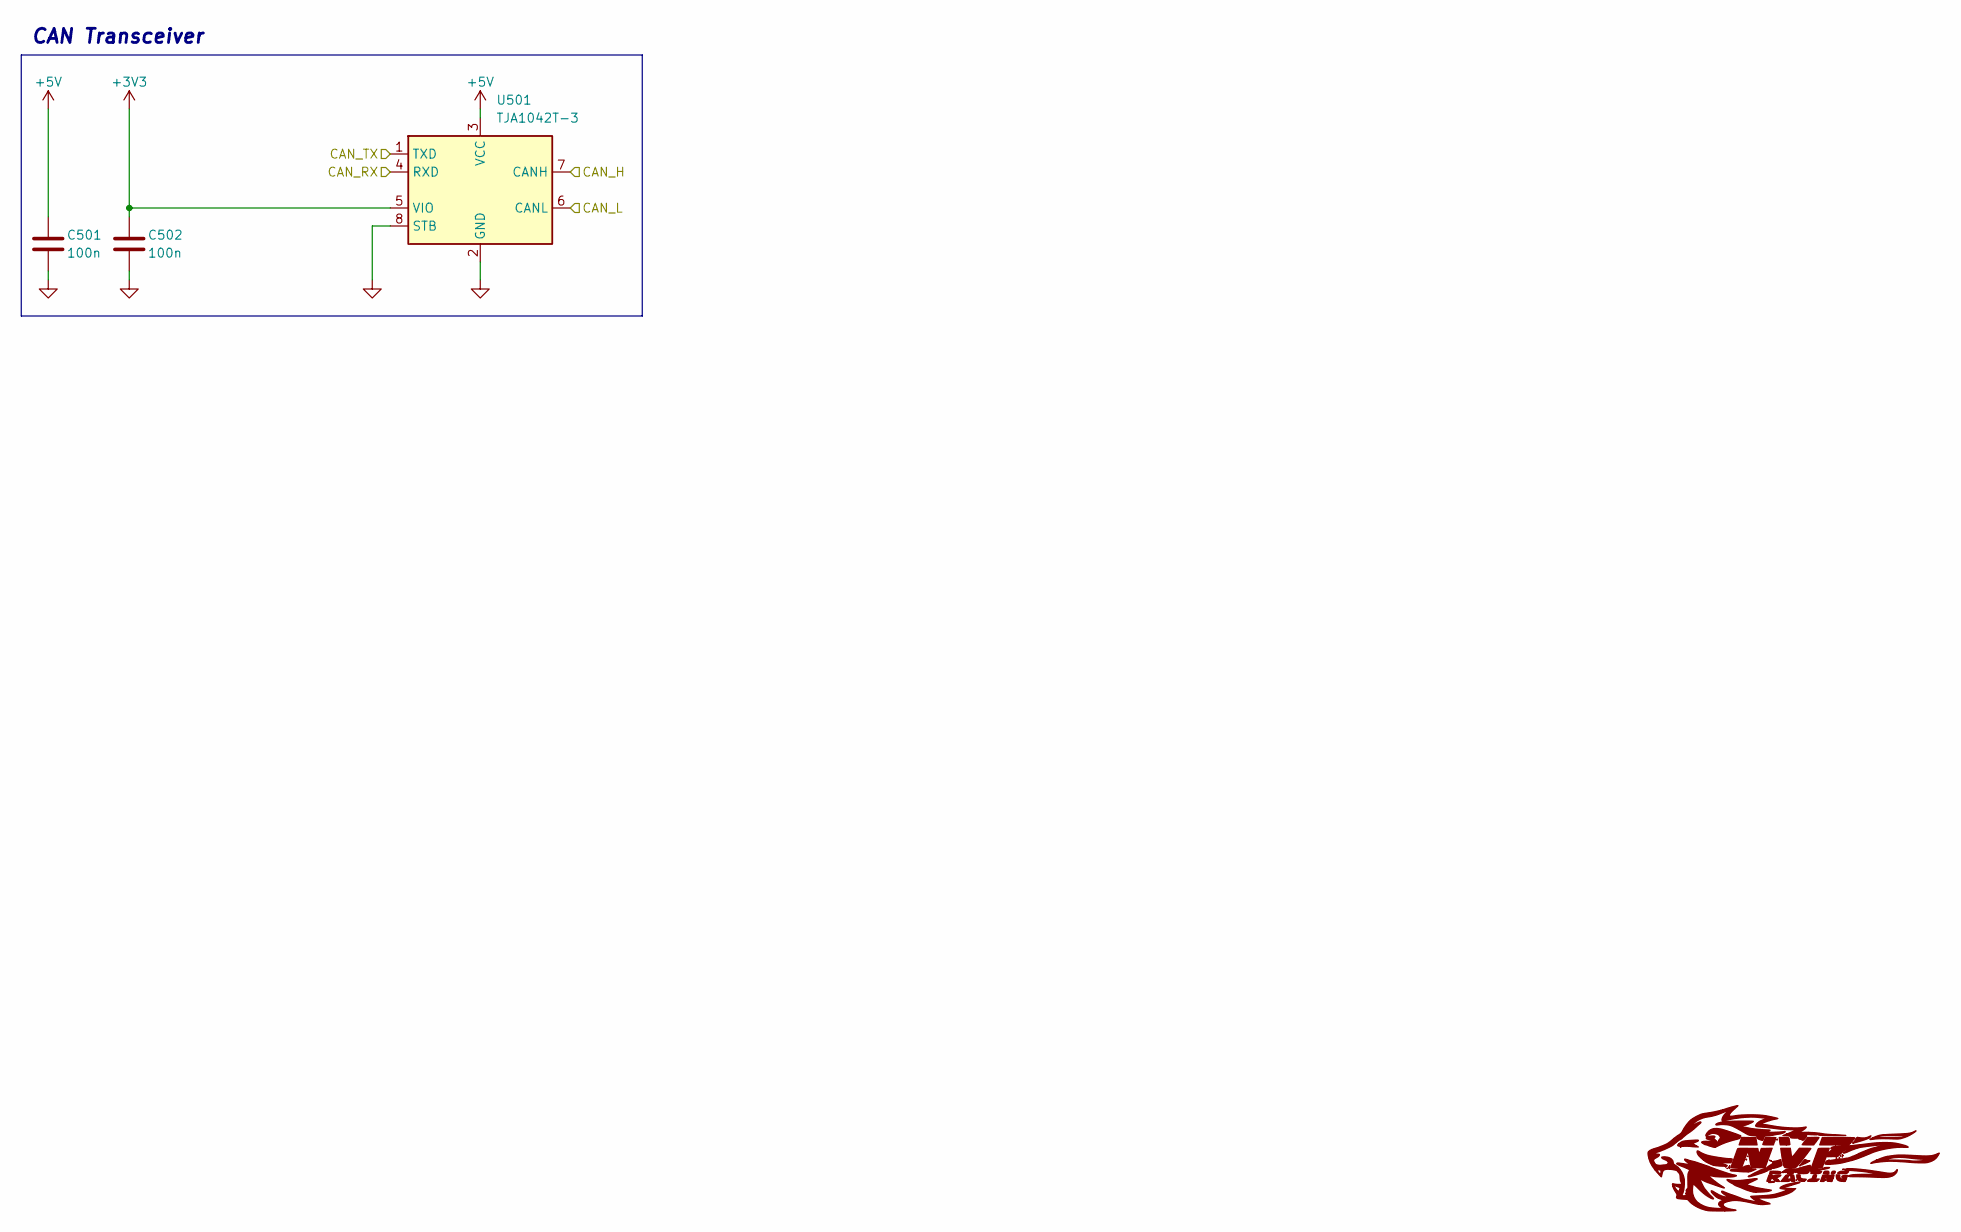
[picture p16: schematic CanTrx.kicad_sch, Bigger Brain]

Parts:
C501, C502: 100n; C_0603_1608Metric; LCSC C14663
U501: TJA1042T-3; SOIC-8_3.9x4.9mm_P1.27mm; LCSC C132227

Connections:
/CAN1_RX: U501.4 (RXD); also elsewhere on the board
/CAN1_TX: U501.1 (TXD); also elsewhere on the board
/CanTrx1/CAN_H: U501.7 (CANH); also elsewhere on the board
/CanTrx1/CAN_L: U501.6 (CANL); also elsewhere on the board
GND: C501.2, C502.2, U501.2 (GND), U501.8 (STB); also elsewhere on the board
MCU-3.3V: C502.1, U501.5 (VIO); also elsewhere on the board
PP-5.0V: C501.1, U501.3 (VCC); also elsewhere on the board

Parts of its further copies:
C601, C602, C701, C702: 100n; C_0603_1608Metric; LCSC C14663
U601, U701: TJA1042T-3; SOIC-8_3.9x4.9mm_P1.27mm; LCSC C132227

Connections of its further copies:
/CAN2_RX: U601.4 (RXD); also elsewhere on the board
/CAN2_TX: U601.1 (TXD); also elsewhere on the board
/CAN3_RX: U701.4 (RXD); also elsewhere on the board
/CAN3_TX: U701.1 (TXD); also elsewhere on the board
/CanTrx2/CAN_H: U601.7 (CANH); also elsewhere on the board
/CanTrx2/CAN_L: U601.6 (CANL); also elsewhere on the board
/CanTrx3/CAN_H: U701.7 (CANH); also elsewhere on the board
/CanTrx3/CAN_L: U701.6 (CANL); also elsewhere on the board
GND: C601.2, C602.2, C701.2, C702.2, U601.2 (GND), U601.8 (STB), U701.2 (GND), U701.8 (STB); also elsewhere on the board
MCU-3.3V: C602.1, C702.1, U601.5 (VIO), U701.5 (VIO); also elsewhere on the board
PP-5.0V: C601.1, C701.1, U601.3 (VCC), U701.3 (VCC); also elsewhere on the board

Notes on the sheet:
CAN Transceiver

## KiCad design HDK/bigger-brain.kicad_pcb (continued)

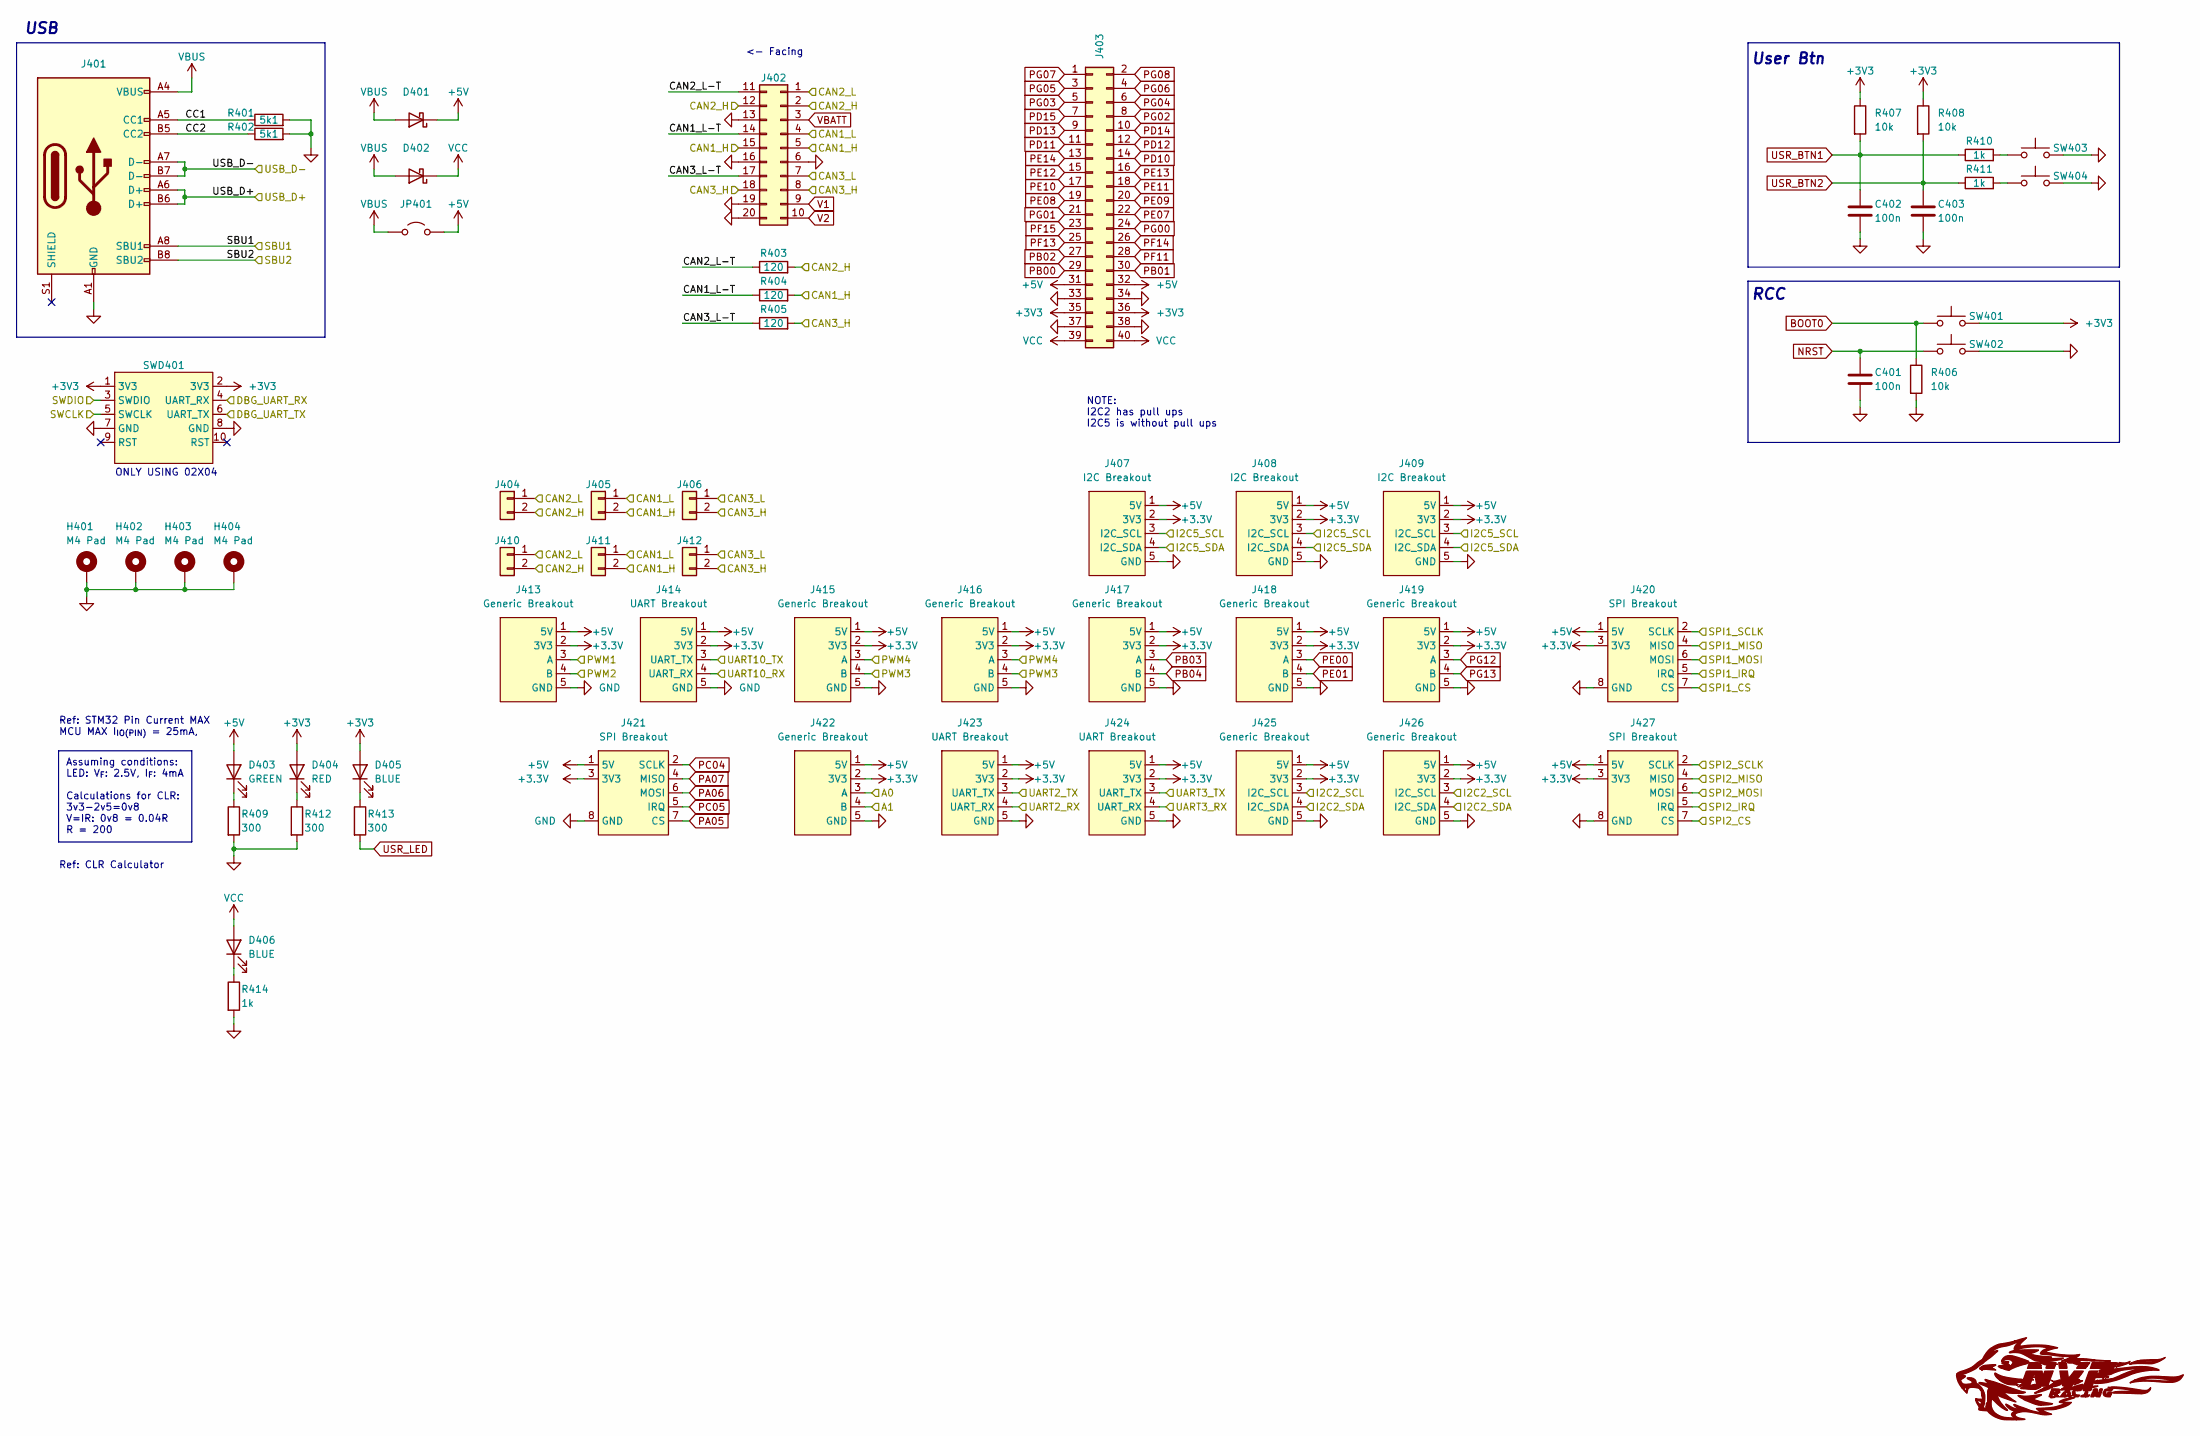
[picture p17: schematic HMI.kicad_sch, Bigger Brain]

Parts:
C401, C402, C403: 100n; C_0603_1608Metric; LCSC C14663
D401, D402: SS14; D_SMA; LCSC C2480
D403: GREEN; LED_0603_1608Metric; LCSC C434423
D404: RED; LED_0603_1608Metric; LCSC C2286
D405, D406: BLUE; LED_0603_1608Metric; LCSC C965807
H401, H402, H403, H404: M4 Pad; MountingHole_4.3mm_M4_DIN965_Pad_TopBottom
J401: USB_C; USBC_HRO_TYPE-C-31-M-12; LCSC C165948
J402: MicroFit_02x10V-H; LCSC C485575
J403: 2.54mm2x20V-H; LCSC C2894981
J404, J405, J406, J410, J411, J412: Conn_01x02; PH_01x02V-H; LCSC C2683610
J407, J408, J409: I2C Breakout; PH_01x05V-H; LCSC C157993
J413, J415, J416, J417, J418, J419, J422, J425, J426: Generic Breakout; PH_01x05V-H; LCSC C157993
J414, J423, J424: UART Breakout; PH_01x05V-H; LCSC C157993
J420, J421, J427: SPI Breakout; PHD_02x04V-H; LCSC C157975
JP401: Jumper_2_Open; PinHeader_1x02_P2.54mm_Vertical
R401, R402: 5k1; R_0603_1608Metric; LCSC C23186
R403, R404, R405: 120; R_1206_3216Metric; LCSC C17909
R406, R407, R408: 10k; R_0603_1608Metric; LCSC C25804
R409, R412, R413: 300; R_0603_1608Metric; LCSC C23025
R410, R411, R414: 1k; R_0603_1608Metric; LCSC C21190
SW401, SW402, SW403, SW404: SW_Push; PushBtn_TS-1187A-B-A-B; LCSC C318884
SWD401: PHD_02x04V-H; LCSC C157975

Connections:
/CanTrx1/CAN_H: J402.5, J402.15, J405.2, J411.2, R404.2; also elsewhere on the board
/CanTrx1/CAN_L: J402.4, J405.1, J411.1; also elsewhere on the board
/CanTrx2/CAN_H: J402.2, J402.12, J404.2, J410.2, R403.2; also elsewhere on the board
/CanTrx2/CAN_L: J402.1, J404.1, J410.1; also elsewhere on the board
/CanTrx3/CAN_H: J402.8, J402.18, J406.2, J412.2, R405.2; also elsewhere on the board
/CanTrx3/CAN_L: J402.7, J406.1, J412.1; also elsewhere on the board
/HMI/CAN1_L-T: J402.14, R404.1
/HMI/CAN2_L-T: J402.11, R403.1
/HMI/CAN3_L-T: J402.17, R405.1
/HMI/CC1: J401.A5 (CC1), R401.1
/HMI/CC2: J401.B5 (CC2), R402.1
/I2C2_SCL: J425.4 (I2C_SDA), J426.4 (I2C_SDA); also elsewhere on the board
/I2C2_SDA: J425.3 (I2C_SCL), J426.3 (I2C_SCL); also elsewhere on the board
/I2C5_SCL: J407.4 (I2C_SDA), J408.4 (I2C_SDA), J409.4 (I2C_SDA); also elsewhere on the board
/I2C5_SDA: J407.3 (I2C_SCL), J408.3 (I2C_SCL), J409.3 (I2C_SCL); also elsewhere on the board
/SPI1_CS: J420.7 (CS); also elsewhere on the board
/SPI1_IRQ: J420.5 (IRQ); also elsewhere on the board
/SPI1_MISO: J420.4 (MISO); also elsewhere on the board
/SPI1_MOSI: J420.6 (MOSI); also elsewhere on the board
/SPI1_SCLK: J420.2 (SCLK); also elsewhere on the board
/SPI2_CS: J427.7 (CS); also elsewhere on the board
/SPI2_IRQ: J427.5 (IRQ); also elsewhere on the board
/SPI2_MISO: J427.4 (MISO); also elsewhere on the board
/SPI2_MOSI: J427.6 (MOSI); also elsewhere on the board
/SPI2_SCLK: J427.2 (SCLK); also elsewhere on the board
/SWCLK: J401.B8 (SBU2), SWD401.5 (SWCLK); also elsewhere on the board
/SWDIO: J401.A8 (SBU1), SWD401.3 (SWDIO); also elsewhere on the board
/UART1_RX: SWD401.4 (UART_RX); also elsewhere on the board
/UART1_TX: SWD401.6 (UART_TX); also elsewhere on the board
/UART2_RX: J423.4 (UART_RX); also elsewhere on the board
/UART2_TX: J423.3 (UART_TX); also elsewhere on the board
/UART3_RX: J424.4 (UART_RX); also elsewhere on the board
/UART3_TX: J424.3 (UART_TX); also elsewhere on the board
/UART10_RX: J414.4 (UART_RX); also elsewhere on the board
/UART10_TX: J414.3 (UART_TX); also elsewhere on the board
BOOT0: R406.1, SW401.1; also elsewhere on the board
GND: C401.2, C402.2, C403.2, H401.1, H402.1, H403.1, H404.1, J401.A1 (GND), J401.A12 (GND), J401.B1 (GND), J401.B12 (GND), J402.6, J402.13, J402.16, J402.19, J402.20, J403.33, J403.34, J403.37, J403.38, J407.5 (GND), J408.5 (GND), J409.5 (GND), J413.5 (GND), J414.5 (GND), J415.5 (GND), J416.5 (GND), J417.5 (GND), J418.5 (GND), J419.5 (GND), J420.8 (GND), J421.8 (GND), J422.5 (GND), J423.5 (GND), J424.5 (GND), J425.5 (GND), J426.5 (GND), J427.8 (GND), R401.2, R402.2, R406.2, R409.2, R412.2, R414.2, SW402.2, SW403.2, SW404.2, SWD401.7 (GND), SWD401.8 (GND); also elsewhere on the board
MCU-3.3V: D404.2 (A), D405.2 (A), J403.35, J403.36, J407.2 (3V3), J408.2 (3V3), J409.2 (3V3), J413.2 (3V3), J414.2 (3V3), J415.2 (3V3), J416.2 (3V3), J417.2 (3V3), J418.2 (3V3), J419.2 (3V3), J420.3 (3V3), J421.3 (3V3), J422.2 (3V3), J423.2 (3V3), J424.2 (3V3), J425.2 (3V3), J426.2 (3V3), J427.3 (3V3), R407.1, R408.1, SW401.2, SWD401.1 (3V3), SWD401.2 (3V3); also elsewhere on the board
NRST: C401.1, SW402.1; also elsewhere on the board
unnamed: D403.1 (K), R409.1
unnamed: D404.1 (K), R412.1
unnamed: D405.1 (K), R413.1
unnamed: D406.1 (K), R414.1
unnamed: R410.2, SW403.1
unnamed: R411.2, SW404.1
PA05: J421.7 (CS); also elsewhere on the board
PA06: J421.6 (MOSI); also elsewhere on the board
PA07: J421.4 (MISO); also elsewhere on the board
PB00: J403.29; also elsewhere on the board
PB01: J403.30; also elsewhere on the board
PB02: J403.27; also elsewhere on the board
PB03: J417.3 (A); also elsewhere on the board
PB04: J417.4 (B); also elsewhere on the board
PC04: J421.2 (SCLK); also elsewhere on the board
PC05: J421.5 (IRQ); also elsewhere on the board
PD10: J403.14; also elsewhere on the board
PD11: J403.11; also elsewhere on the board
PD12: J403.12; also elsewhere on the board
PD13: J403.9; also elsewhere on the board
PD14: J403.10; also elsewhere on the board
PD15: J403.7; also elsewhere on the board
PE00: J418.3 (A); also elsewhere on the board
PE01: J418.4 (B); also elsewhere on the board
PE05: J413.4 (B); also elsewhere on the board
PE06: J413.3 (A); also elsewhere on the board
PE07: J403.22; also elsewhere on the board
PE08: J403.19; also elsewhere on the board
PE09: J403.20; also elsewhere on the board
PE10: J403.17; also elsewhere on the board
PE11: J403.18; also elsewhere on the board
PE12: J403.15; also elsewhere on the board
PE13: J403.16; also elsewhere on the board
PE14: J403.13; also elsewhere on the board
PF02: J415.3 (A), J416.3 (A); also elsewhere on the board
PF03: J415.4 (B), J416.4 (B); also elsewhere on the board
PF04: J422.3 (A); also elsewhere on the board
PF05: J422.4 (B); also elsewhere on the board
PF11: J403.28; also elsewhere on the board
PF13: J403.25; also elsewhere on the board
PF14: J403.26; also elsewhere on the board
PF15: J403.23; also elsewhere on the board
PG00: J403.24; also elsewhere on the board
PG01: J403.21; also elsewhere on the board
PG02: J403.8; also elsewhere on the board
PG03: J403.5; also elsewhere on the board
PG04: J403.6; also elsewhere on the board
PG05: J403.3; also elsewhere on the board
PG06: J403.4; also elsewhere on the board
PG07: J403.1; also elsewhere on the board
PG08: J403.2; also elsewhere on the board
PG12: J419.3 (A); also elsewhere on the board
PG13: J419.4 (B); also elsewhere on the board
PP-5.0V: D401.1 (K), D403.2 (A), J403.31, J403.32, J407.1 (5V), J408.1 (5V), J409.1 (5V), J413.1 (5V), J414.1 (5V), J415.1 (5V), J416.1 (5V), J417.1 (5V), J418.1 (5V), J419.1 (5V), J420.1 (5V), J421.1 (5V), J422.1 (5V), J423.1 (5V), J424.1 (5V), J425.1 (5V), J426.1 (5V), J427.1 (5V), JP401.2 (B); also elsewhere on the board
USB_D+: J401.A6 (D+), J401.B6 (D+); also elsewhere on the board
USB_D-: J401.A7 (D-), J401.B7 (D-); also elsewhere on the board
USR_BTN1: C402.1, R407.2, R410.1; also elsewhere on the board
USR_BTN2: C403.1, R408.2, R411.1; also elsewhere on the board
USR_LED: R413.2; also elsewhere on the board
V1: J402.9; also elsewhere on the board
V2: J402.10; also elsewhere on the board
VBATT: J402.3; also elsewhere on the board
VBUS: D401.2 (A), D402.2 (A), J401.A4 (VBUS), J401.A9 (VBUS), J401.B4 (VBUS), J401.B9 (VBUS), JP401.1 (A)
VCC: D402.1 (K), D406.2 (A), J403.39, J403.40; also elsewhere on the board

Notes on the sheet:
NOTE: I2C2 has pull ups I2C5 is without pull ups
USB
<- Facing
Ref: STM32 Pin Current MAX MCU MAX I_{IO(PIN)} = 25mA,
Ref: CLR Calculator
Assuming conditions: LED: V_{F}: 2.5V, I_{F}: 4mA Calculations for CLR: 3v3-2v5=0v8 V=IR: 0v8 = 0.04R R = 200
ONLY USING 02X04
RCC
User Btn

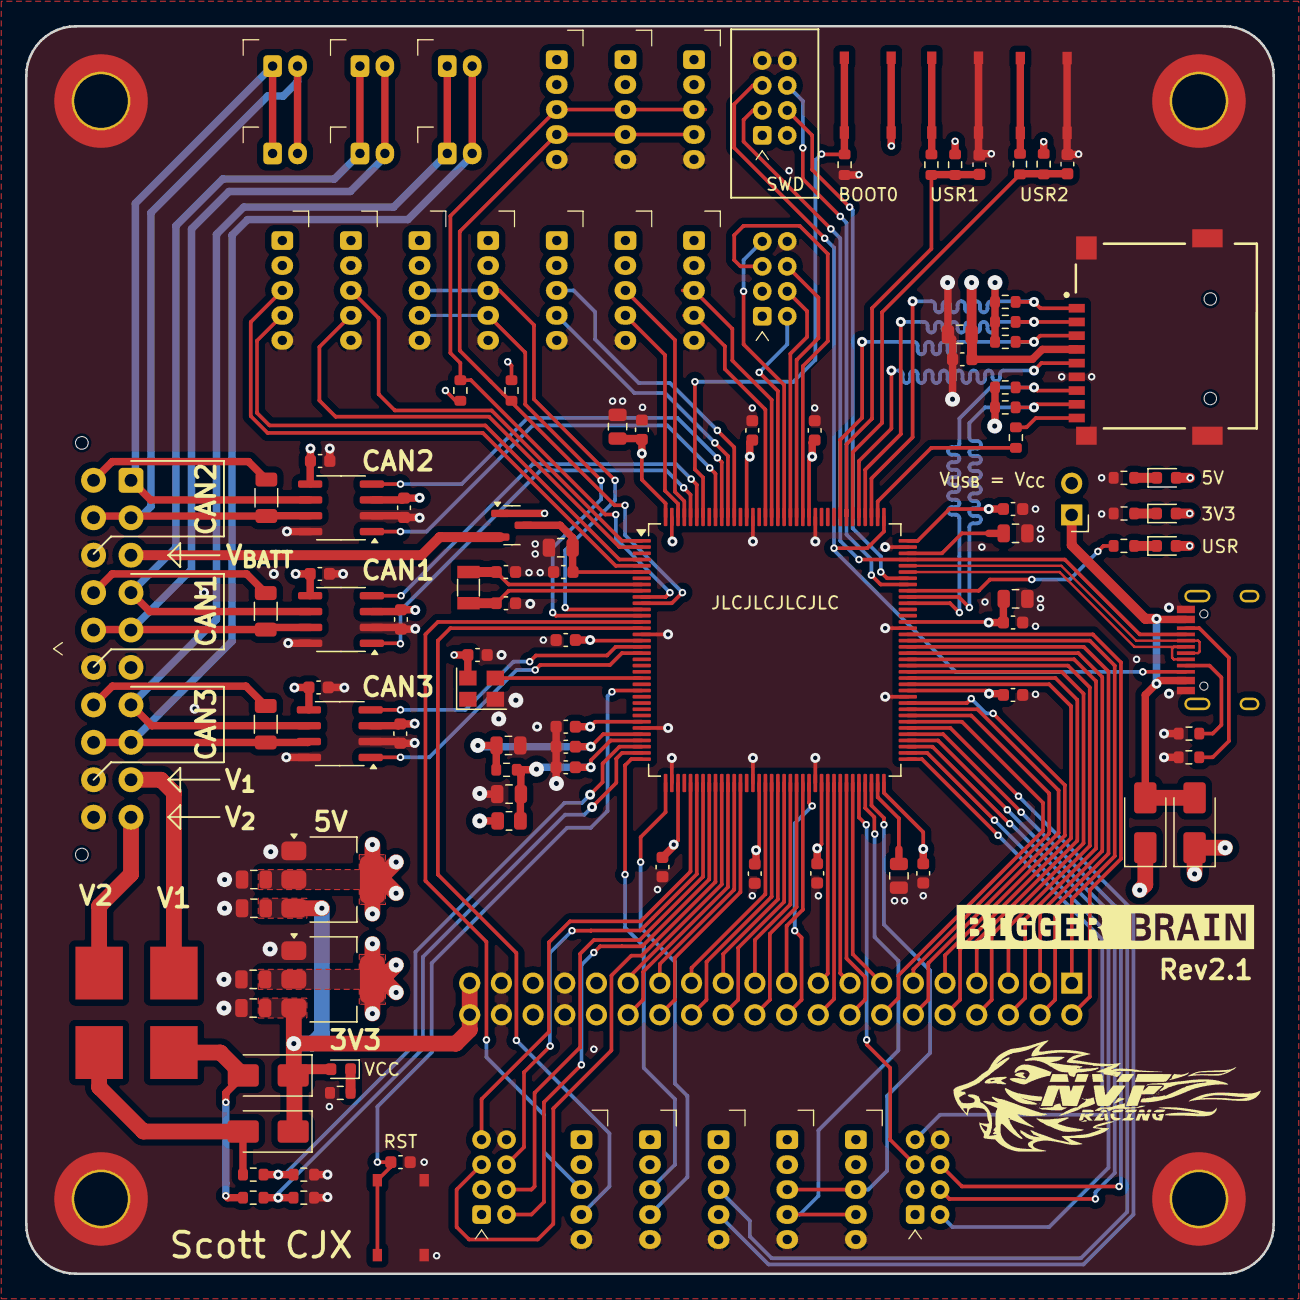
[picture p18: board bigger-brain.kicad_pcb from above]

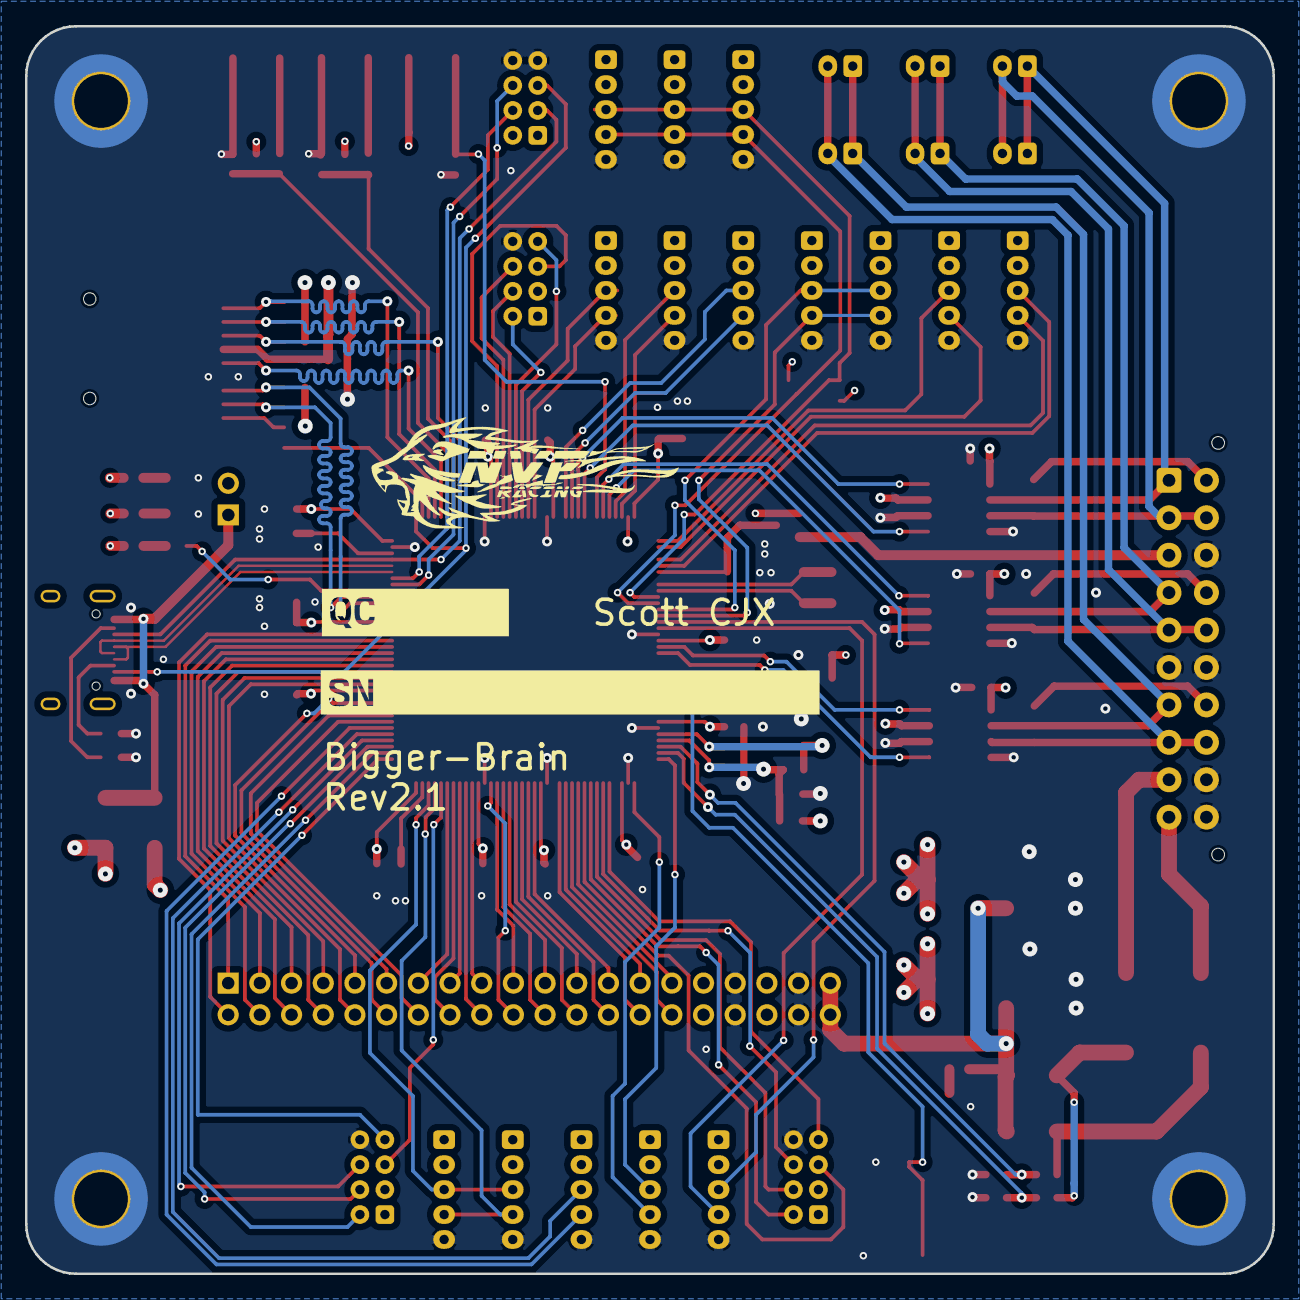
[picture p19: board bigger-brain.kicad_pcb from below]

Board: 4 copper layers, 100.0 x 100.0 mm, 128 parts (2 on the bottom side), 129 nets.

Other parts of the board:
kibuzzard-65AE28D0: G***; kibuzzard-65AE28D0
kibuzzard-65BA50A4: G***; kibuzzard-65BA50A4
kibuzzard-65BA50D8: G***; kibuzzard-65BA50D8

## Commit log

2024-01-24 updated WIP
    [HMI.kicad_sch, Power.kicad_sch, bigger-brain.kicad_pcb]
2024-01-31 added rev1-final
    [CanTrx.kicad_sch, HMI.kicad_sch, Power.kicad_sch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]
2024-03-01 freeze rev1.1
    [CanTrx.kicad_sch, HMI.kicad_sch, Power.kicad_sch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]
2024-03-05 updated rev2
    [CanTrx.kicad_sch, HMI.kicad_sch, Power.kicad_sch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]
2024-03-17 freeze rev2
    [CanTrx.kicad_sch, HMI.kicad_sch, Power.kicad_sch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]
2024-03-18 updated docs
    [bigger-brain-B_Cu.gbr, bigger-brain-B_Mask.gbr, bigger-brain-B_Paste.gbr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]
2024-04-08 updated rev2.1
    [CanTrx.kicad_sch, HMI.kicad_sch, Power.kicad_sch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]
2024-04-08 added fab and ibom
    [HMI.kicad_sch, bigger-brain.kicad_pcb, bom.csv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]
